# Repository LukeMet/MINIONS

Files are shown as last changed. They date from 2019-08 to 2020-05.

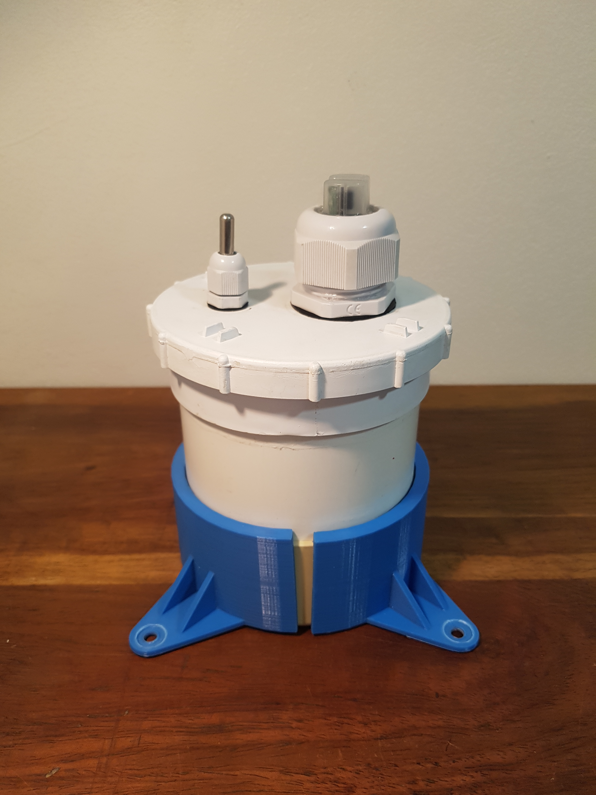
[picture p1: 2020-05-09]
Photos/Construction/2_Lower_SensorModule(i).jpg

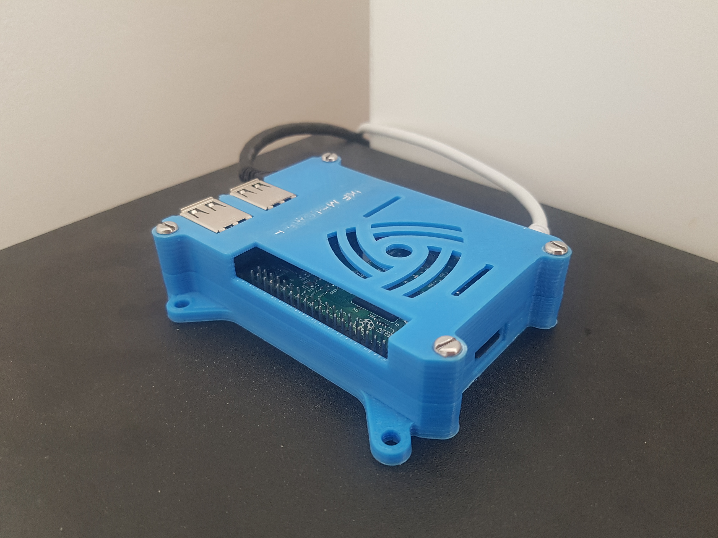
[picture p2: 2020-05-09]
Photos/Construction/4_Server.jpg

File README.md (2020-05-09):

# MINIONS: MarINe Internet Of Nodes Specification
### Luke Metcalfe UCT Mechatronics Final Year Project 2019

Defined a common electrical, mechanical, operational and communication specification for IoT marine monitoring devices and built two prototypes according to the specification. The system comprised of a marine buoy located at sea (Transmitter Node), a base station on land (Receiver Node), and a nearby server. The buoy was equipped with temperature and turbidity sensors, an ESP32 microcontroller, a power supply and management module, and a wireless communications module. Data was transmitted from the buoy to the base station via LoRaWAN. The base station displayed data on an OLED screen and interacted with the server using the MQTT protocol to upload data to an online user interface. Through the interface, users could view all data graphically, receive status updates, and control the buoy remotely.

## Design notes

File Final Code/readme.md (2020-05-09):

Transmitter Node relates to the buoy that was deployed at sea.
Receiver Node relates to the base station on land.
Node-RED Flow relates to the Node-RED Dashboard/user interface.

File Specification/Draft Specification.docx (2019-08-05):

1. General Requirements
  1.1 Designs deviating from the MINIONs specification must ensure complete interoperability and compatibility with existing designs.
  1.2 All parts shall remain attached to the MINIONs during launch and operation. No additional debris shall be created. No MINION may shed any solids or liquids that could be deemed pollution.
  1.3 Total stored chemical energy must not exceed 100 Watt-Hours. (United States Code of Federal Regulations – 49 CFR 175) (100Wh is equivalent to a 5V, 20000mAh battery)
2. Mechanical Requirements
  2.1 General Mechanical Requirements
    2.1.1 MINIONs enclosures should be IP68 and NEMA 6P rated against dust and water for all devices to be deployed above 5m depth. For devices being deployed beyond this depth, designers need to ensure that the enclosure is waterproof at the depth for the duration of the mission at least. (In accordance with ISO 20653:2013 and IEC 60529)
    2.1.2 The enclosure must be fastened to the platform with M4 (ISO 261:1998) nuts and bolts.
    2.1.3 The configuration and physical dimensions shall be defined at a later stage.
    2.1.4 A maximum of 8 MINIONS enclosures can be accommodated on the MINIONS platform.
  2.2 Materials
    2.2.1 All metals used in the construction of the enclosure and platform must be either Type 316 stainless steel (Society of Automotive Engineers (SAE) Steel Grades) or 5052 aluminium (The Alloy Association Inc. International Alloy Designations for Wrought Aluminium Alloys. 5052 formerly designated as AlMg2.5 in ISO 209-1.)
    2.2.2 Where other metals are used, the designer must ensure the chosen metals have similar or better corrosion resistance in marine environments in accordance with ISO9223 and ISO9226. (include corrosion rates of 316 and 5052?)
    2.2.3 All plastic must be HDPE, LDPE or PETG (if 3D printed). (The Society of the Plastics Industry (SPI) Plastic Types)
    2.2.4 Where other plastics are used, the designer must ensure that the material has a water absorption rate less than 0.30% in accordance with ISO62.

ISO 15314:2018 - Plastics -- Methods for marine exposure

3. Electrical Requirements
  3.1 The communication protocol for external busses shall be RS485.
  3.2 The standard supply voltage should be 5V. Many components require this voltage, and this allows both 5V and 3.3V components/peripherals to be used (with the use of level shifters, regulators etc).
  3.3 All MINIONS devices must incorporate battery circuit protection to avoid unbalanced cell conditions. The protection circuitry should ensure charge and discharge voltage limits, charge and discharge current limits and cell-balancing if multiple cells are used. Correct charging and discharging procedures/cycles, specific to the chosen battery, must be followed.
4. Operational Requirements
  4.1 No MINION may shed any solids or liquids that could be deemed pollution.
  4.2 All equipment that is deployed must be retrieved once the mission is complete. No part of the MINION node/s, platform, mooring system, or any other part must remain at sea once the mission is complete.
  4.3 MINIONS must comply with their country’s radio licence agreements and restrictions.
    4.3.1 Standardise LoRa? – Other devices will only be able to talk to mine if they use LoRa

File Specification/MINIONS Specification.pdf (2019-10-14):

# MINIONS

# MarINe Internet Of Nodes Specification

# 1 Introduction

### 1.1 Overview

The MINIONS Specification outlines a general, operational, electrical and mechanical specification to provide a standard for the development of Internet of Things (IoT) marine monitoring devices. The specification lists several requirements of systems and proposes a mechanical design to encourage uniformity and interoperability between devices and networks, as well as the open development of projects between groups.

### 1.2 Purpose

The primary purpose of this document is to define standards for IoT marine monitoring devices to ensure their suitability to the environment, aid cooperation and integration of projects, accelerate development of devices and networks, and accelerate advances in the field.

# 2 Requirements

### 2.1 General Requirements

1.1. Designs deviating from the MINIONS specification must ensure complete interoperability and compatibility with existing designs.
1.2. All parts shall remain attached to the device during launch and operation. No additional debris shall be created.
1.3. Total stored chemical energy must not exceed 100 Watt-Hours [1].

### 2.2 Mechanical Requirements

### 2.2.1 General Mechanical Requirements

1.3.1.Floating platforms shall consist of a floatation device, mounting platform, enclosures and mooring system
1.3.2.Enclosures must be IP68 and NEMA 6P rated against dust and water for all devices to be deployed above 5m depth. For devices being deployed beyond this depth, designers need to ensure that the enclosure is waterproof at the chosen depth for at least the duration of the mission [2][3].

1.3.3.The floatation device used shall be a SOLAS-compliant lifebuoy
1.3.4.The mounting platform shall be secured in the middle of the flotation device. 1.3.5.The platform shall accommodate up to 4 enclosures on its upper and lower surfaces, with a maximum of 8 enclosures in total.
1.3.6.Enclosures shall be fastened to the platform with four M6 [4] nuts, bolts and washers.
Floatation device, mounting platform and enclosure physical dimensions are specified in “

1.3.7.Physical Dimensions of Mechanical Components”.

### 2.2.2 Materials

1.3.8.All metals used in the construction of the enclosure and platform shall be either Type 316 stainless steel or 5052 aluminium.
1.3.9.Where other metals are used, the designer must ensure the chosen metals have similar or better corrosion resistance in marine environments in accordance with ISO 9223 [5] and ISO 9226 [6].
1.3.10. All plastic must be HDPE, LDPE or PETG (if 3D printed).
1.3.11. Where other plastics are used, the designer must ensure that the material has a water absorption rate less than 0.30% in accordance with ISO62 [7], UV resistance similar to that of HDPE, LDPE and PETG, and that the plastic is durable for use at sea in accordance with ISO 15314:2018 [8].

### 2.3 Electrical Requirements

1.4. The communication protocol for external busses shall be RS485.
1.5. No standard supply voltage is specified, as different components require a wide array of supply voltages. Instead, designers must ensure a stable, regulated supply that is able to output the required voltage and current of each component. Special consideration in this regard must be given when interfacing with other MINIONS devices.
1.6. Batteries must comply with Requirement 1.3.
1.7. All MINIONS compliant devices that use batteries must incorporate battery circuit protection to avoid unbalanced cell conditions. The protection circuitry should ensure charge and discharge voltage limits, charge and discharge current limits and cellbalancing if multiple cells are used. Correct charging and discharging procedures/cycles specific to the chosen battery must be followed.
1.8. Wireless communications modules may use WiFi, Bluetooth, LoRa or MQTT technologies.

### 2.4 Operational Requirements

1.9. All equipment that is deployed must be retrieved once the project is complete. No part of the system’s node/s, platform, mooring system, or any other part must remain at sea.
1.10. Approval must be acquired before deploying networks.
1.11. Systems must comply with their country’s radio licence agreements and restrictions.

# 3 Physical Dimensions of Mechanical Components

### 3.1 Floatation device

The floatation device used shall be a SOLAS-compliant lifebuoy, with an outer diameter no greater than 800mm, and inner diameter no less than 400mm [9].

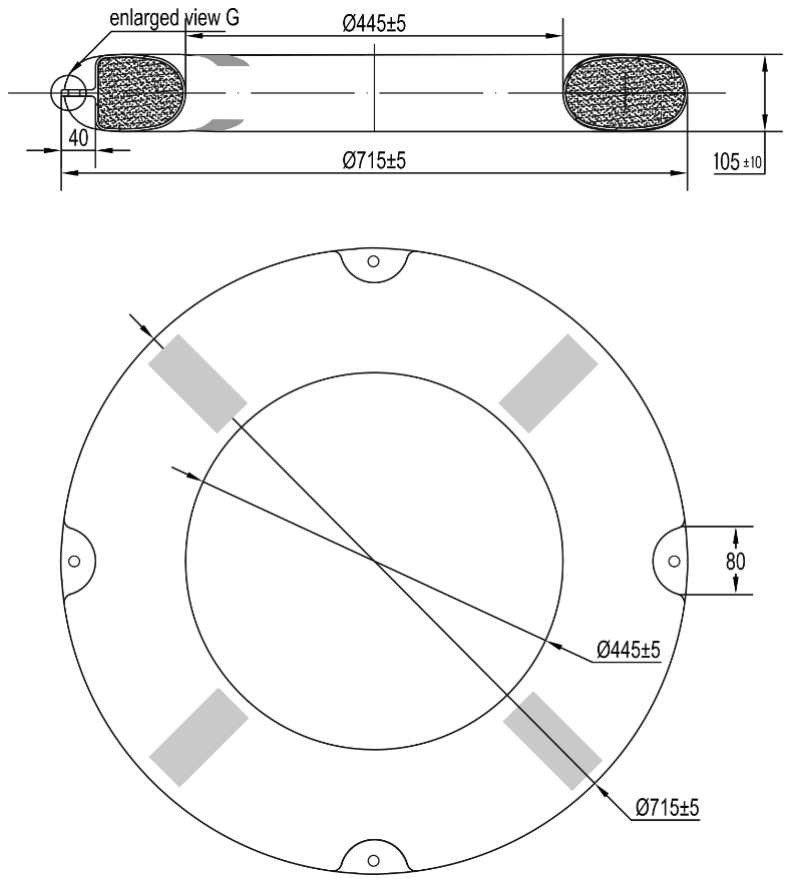
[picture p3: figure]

Figure 1: Illustration of a SOLAS-compliant lifebuoy [10]

### 3.2 Mounting platform

The mounting platform must be circular in shape and cut to fit the internal diameter of the flotation device. It must be possible to fit 4 MINIONS enclosures on each surface. Holes shall be drilled to for the tabs of the MINIONS enclosure must measure 6mm in diameter. The size and layout of the mounting platform are shown below.

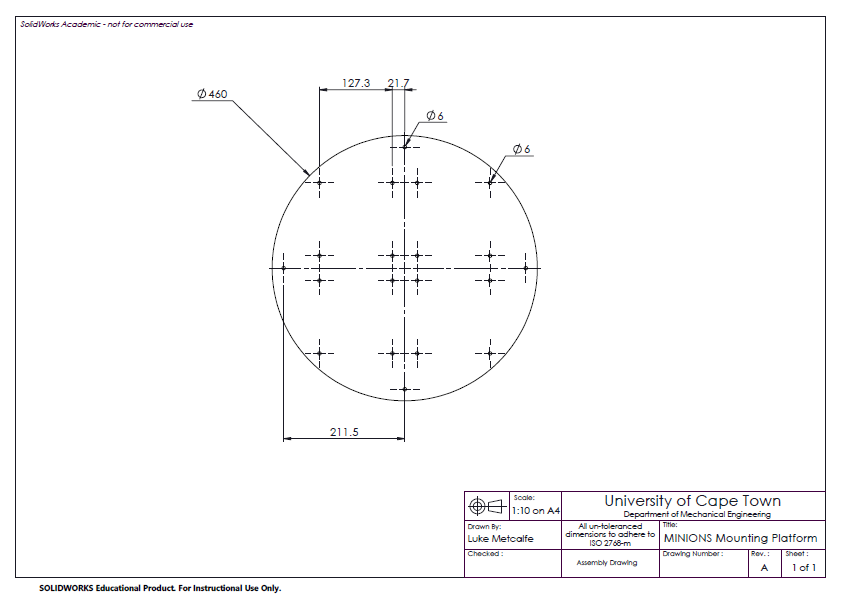
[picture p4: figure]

Figure 2: Top view of the MINIONS mounting platform

### 3.3 Enclosure

The enclosure shall be cylindrical in shape, with a height and diameter of 110mm. The enclosure must have four equally-spaced tabs at its bottom in order to be secured to the mounting platform. The tabs shall have 6mm holes, and the holes should have a pitch of 127.3mm. This corresponds to a diagonal pitch of 180mm apart. Mechanical drawings of the enclosure are shown in Figure 3 to Figure 5 below.

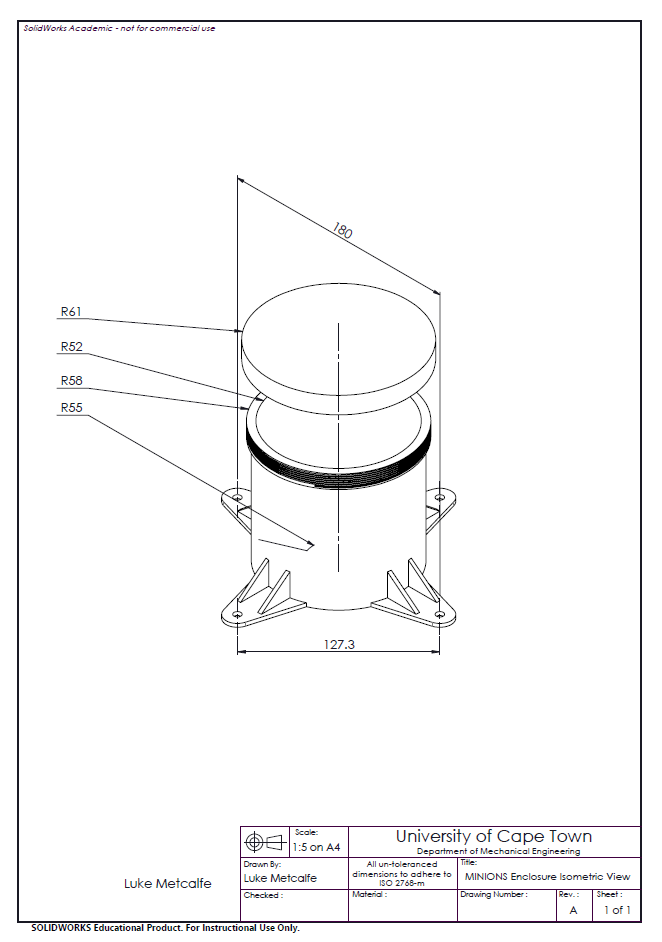
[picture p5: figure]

Figure 3: Isometric view of the MINIONS enclosure

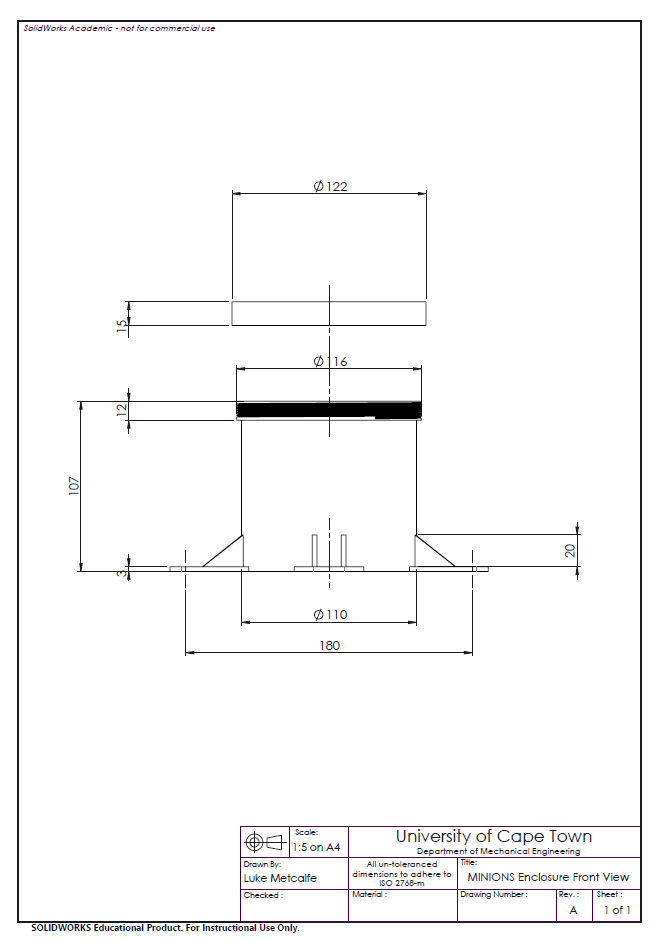
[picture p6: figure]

Figure 4: Front view of the MINIONS enclosure

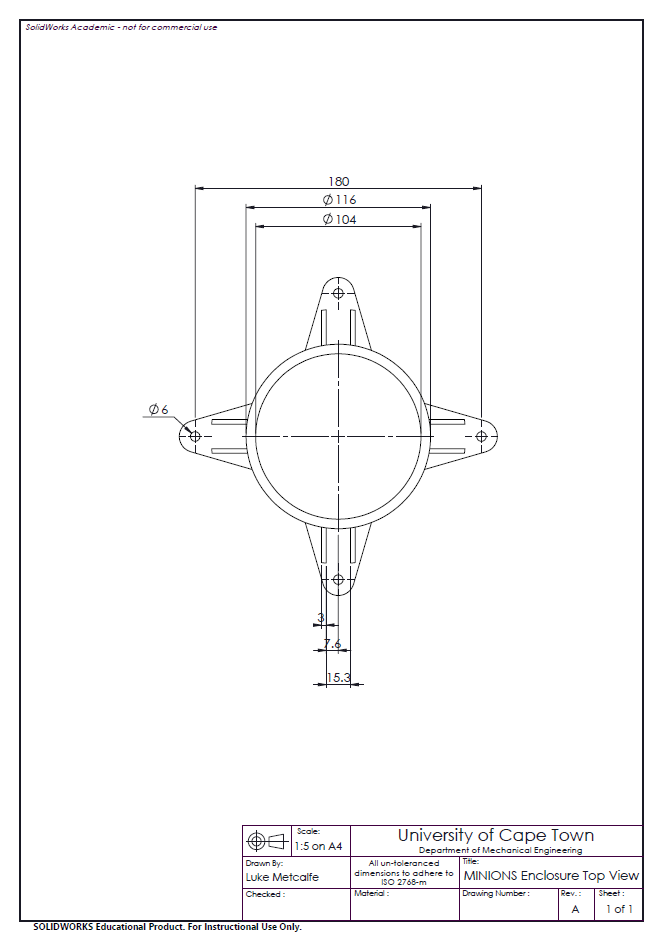
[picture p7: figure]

Figure 5: Top view of the MINIONS enclosure

### 3.4 Assembly

The assembly of the enclosures and mounting platform is shown in Figure 6 below.

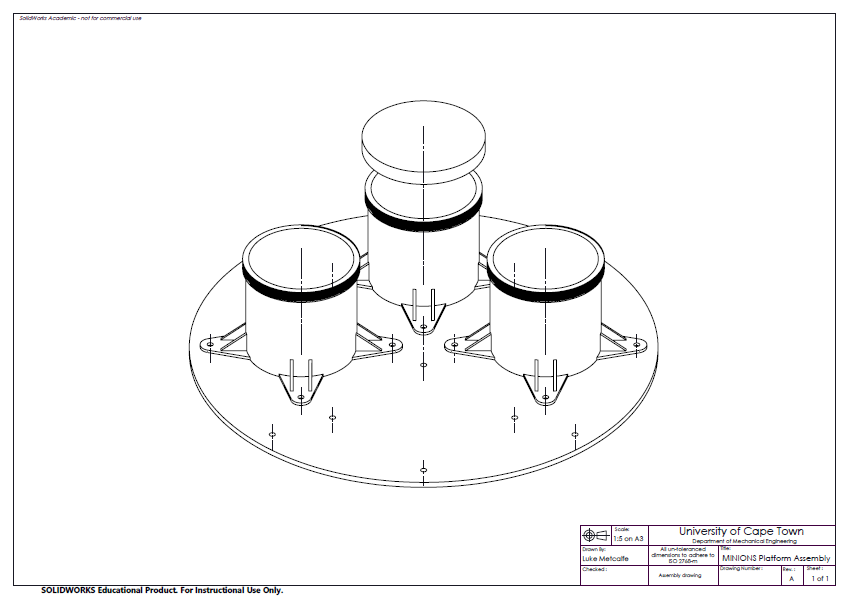
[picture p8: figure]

Figure 6: Isometric view of the assembly of the MINIONS mounting platform and three MINIONS enclosures

# 4 Appendix

References and Cited Standards.

[1] “49 CFR Part 175 - CARRIAGE BY AIRCRAFT | CFR | US Law | LII / Legal Information
Institute.” [Online]. Available: https://www.law.cornell.edu/cfr/text/49/part-175. [Accessed: 12-Oct-2019].
[2] “ISO - ISO 20653:2013 - Road vehicles — Degrees of protection (IP code) — Protection of electrical equipment against foreign objects, water and access.” [Online]. Available: https://www.iso.org/standard/58048.html. [Accessed: 12-Oct-2019].
[3] “IEC 60529:1989+AMD1:1999+AMD2:2013 CSV | IEC Webstore | water management,
smart city, rural electrification.” [Online]. Available: https://webstore.iec.ch/publication/2452. [Accessed: 12-Oct-2019].
[4] “ISO - ISO 261:1998 - ISO general purpose metric screw threads — General plan.” [Online]. Available: https://www.iso.org/standard/4165.html. [Accessed: 12-Oct-2019].
[5] “ISO - ISO 9223:2012 - Corrosion of metals and alloys — Corrosivity of atmospheres — Classification, determination and estimation.” [Online]. Available: https://www.iso.org/standard/53499.html. [Accessed: 12-Oct-2019].
[6] “ISO - ISO 9226:2012 - Corrosion of metals and alloys — Corrosivity of atmospheres — Determination of corrosion rate of standard specimens for the evaluation of corrosivity.” [Online]. Available: https://www.iso.org/standard/53502.html. [Accessed: 12-Oct-2019].
[7] “ISO - ISO 62:2008 - Plastics — Determination of water absorption.” [Online]. Available: https://www.iso.org/standard/41672.html. [Accessed: 12-Oct-2019].
[8] “ISO - ISO 15314:2018 - Plastics — Methods for marine exposure.” [Online]. Available: https://www.iso.org/standard/74668.html. [Accessed: 12-Oct-2019].
[9] “International Convention for the Safety of Life at Sea (SOLAS), 1974.” [Online]. Available: http://www.imo.org/en/About/Conventions/ListOfConventions/Pages/International-Convention-for-the-Safety-of-Life-at-Sea-(SOLAS),-1974.aspx. [Accessed: 12-Oct-2019].
[10] Lalizas, “LALIZAS Lifebuoy Ring SOLAS, with Reflective Tape.” [Online]. Available: https://www.lalizas.com/product/25-lifebuoy-rings/2833-lalizas-lifebuoy-ring-solaswith-reflective-tape. [Accessed: 12-Oct-2019].

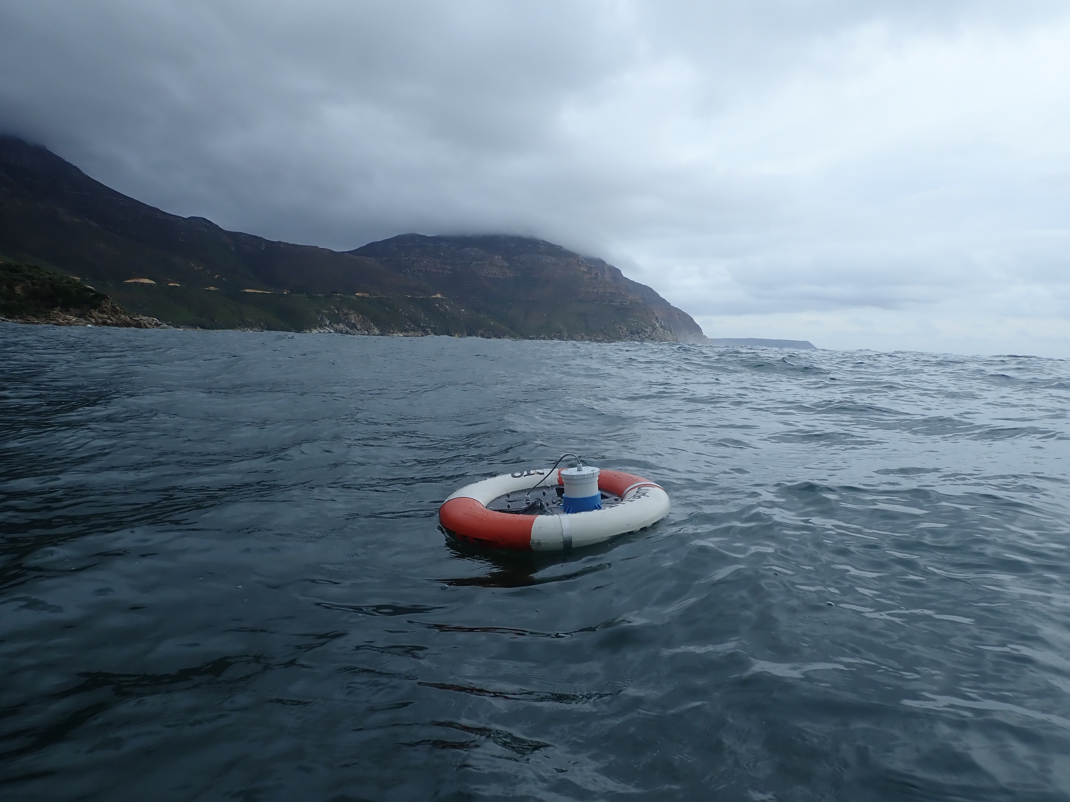
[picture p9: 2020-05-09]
Photos/Deployment/Deploy4.JPG

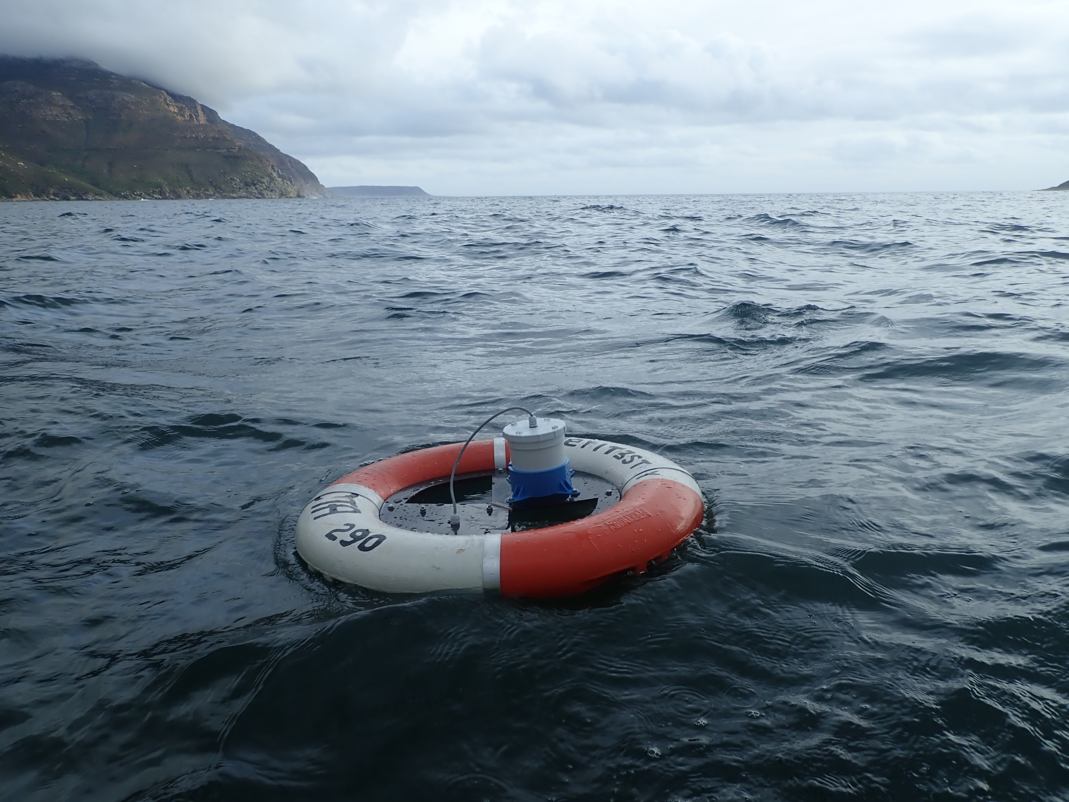
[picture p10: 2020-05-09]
Photos/Deployment/Deploy3.JPG

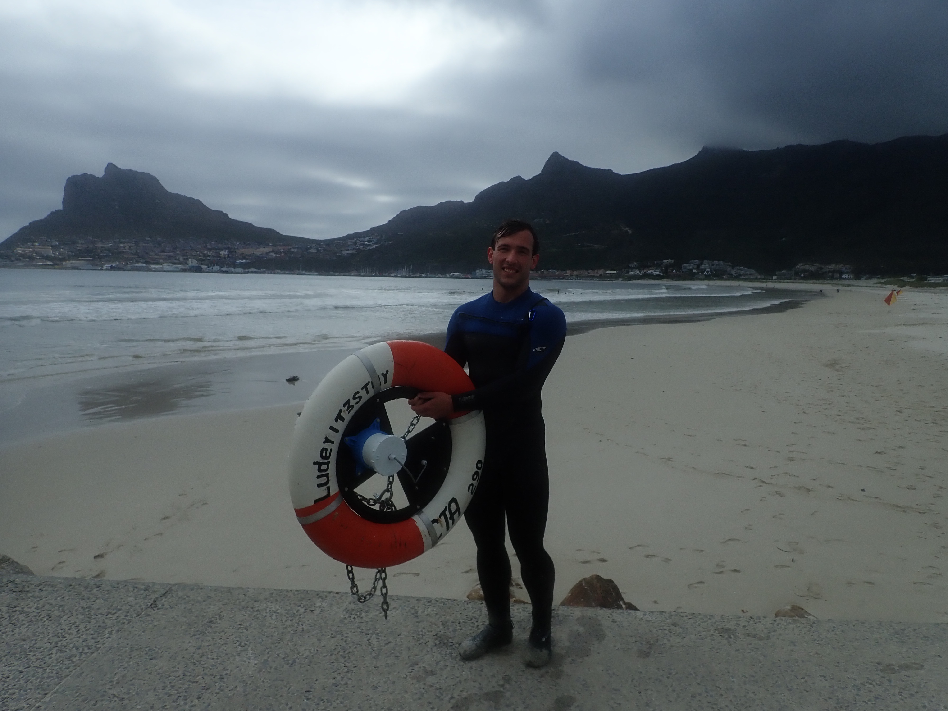
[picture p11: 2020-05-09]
Photos/Deployment/Retreive3.JPG

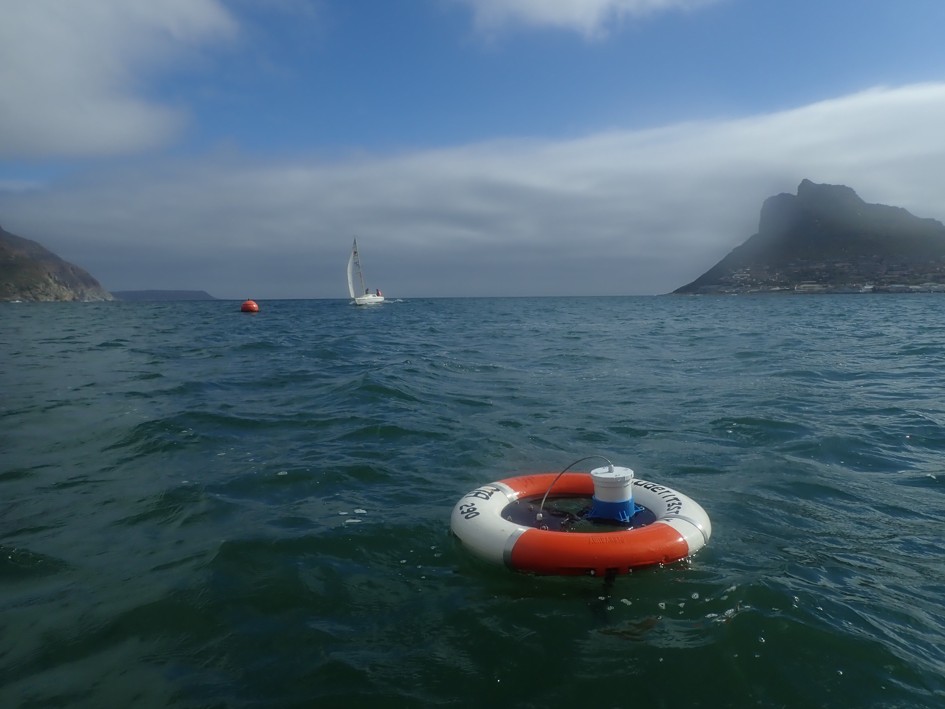
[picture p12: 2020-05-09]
Photos/Deployment/Retreive1.JPG

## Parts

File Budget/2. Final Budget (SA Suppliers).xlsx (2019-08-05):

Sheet: Budget
Complete System
Item No. | Description | Store | Quantity | Unit Cost | Total Cost | Purchase Link
1 | EVAL BOARD FOR ESP-WROOM-32 | Digikey | 2 | 146.1 | 292.2 | https://www.digikey.co.za/product-detail/en/espressif-systems/ESP32-DEVKITC-32D/1965-1000-ND/9356990 | 1
2 | RFM95W LORA RADIO TRANSCEIVER BR (Adafruit) | Digikey | 2 | 291.47 | 582.94 | https://www.digikey.co.za/product-detail/en/adafruit-industries-llc/3072/1528-1667-ND/6005357 | 1
4 | RF Solutions Straight RSMAReverse;Female, Solder Termination, Reverse Polarity | RS Components | 2 | 39.17 | 78.34 | https://za.rs-online.com/web/p/sma-connectors/1258192/ | 1
3 | RF Solutions Antenna FLEXI-SMA-868, Whip SMA 868MHz | RS Components | 2 | 145.1 | 290.2 | https://za.rs-online.com/web/p/telemetry-antennas/0542551/ | 1
5 | GRAVITY: ANALOG TURBIDITY SENSOR | Digikey | 1 | 149.02 | 149.02 | https://www.digikey.co.za/products/en?keywords=sen0189 | 1
6 | DS18B20 WATERPROOF TEMPERATURE SENSOR | DIY Electronics | 1 | 44.95 | 44.95 | https://www.diyelectronics.co.za/store/temperature-sensors/297-waterproof-temperature-sensor.html | 1
 |  |  |  |  | 1437.65
Top Choice
Item No. | Description | Store | Quantity | Unit Cost | Total Cost | Purchase Link
1 | EVAL BOARD FOR ESP-WROOM-32 | Digikey | 2 | 146.1 | 292.2 | https://www.digikey.co.za/product-detail/en/espressif-systems/ESP32-DEVKITC-32D/1965-1000-ND/9356990 | 1
2 | RFM95W LORA RADIO TRANSCEIVER BR (Adafruit) | Digikey | 2 | 291.47 | 582.94 | https://www.digikey.co.za/product-detail/en/adafruit-industries-llc/3072/1528-1667-ND/6005357 | 1
4 | RF Solutions Straight RSMAReverse;Female, Solder Termination, Reverse Polarity | RS Components | 2 | 39.17 | 78.34 | https://za.rs-online.com/web/p/sma-connectors/1258192/ | 1
3 | RF Solutions Antenna FLEXI-SMA-868, Whip SMA 868MHz | RS Components | 2 | 145.1 | 290.2 | https://za.rs-online.com/web/p/telemetry-antennas/0542551/ | 1
5 | GRAVITY: ANALOG TURBIDITY SENSOR | Digikey | 1 | 149.02 | 149.02 | https://www.digikey.co.za/products/en?keywords=sen0189 | 1
6 | DS18B20 WATERPROOF TEMPERATURE SENSOR | DIY Electronics | 1 | 44.95 | 44.95 | https://www.diyelectronics.co.za/store/temperature-sensors/297-waterproof-temperature-sensor.html | 1
 |  |  |  |  | 1437.65

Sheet: Data
Description | Store | Unit Cost | Purchase Link
Micros
ESP-32 Dev Board | Micro Robotics | 159 | https://www.robotics.org.za/espressif%20/ESP-32DEV | 1
BSK ESP-32 WIFI B/T DEV BOARD | Communica | 175 | https://www.communica.co.za/products/bsk-esp-32-wifi-b-t-dev-board | 1
EVAL BOARD FOR ESP-WROOM-32 | Digikey | 146.1 | https://www.digikey.co.za/product-detail/en/espressif-systems/ESP32-DEVKITC-32D/1965-1000-ND/9356990 | 1
LoRa Modules
SX1278 LoRa Module 433Mhz 10Km | Micro Robotics | 139 | https://www.robotics.org.za/%20SX1278-433?search=lora | 1
RFM95W LORA RADIO TRANSCEIVER BR (Adafruit) | Digikey | 291.47 | https://www.digikey.co.za/product-detail/en/adafruit-industries-llc/3072/1528-1667-ND/6005357 | 1
Adafruit RFM95W LoRa Radio Transceiver Breakout - 868 or 915 MHz | Micro Robotics | 398 | https://www.robotics.org.za/AF3072?search=lora | 1
Antennae
RF Solutions Antenna FLEXI-SMA-868, Whip SMA 868MHz | RS Components | 145.1 | https://za.rs-online.com/web/p/telemetry-antennas/0542551/ | 1
Connectors
ACM IPEX TO SMA ANTENA ADPT 10CM | Communica | 39 | https://www.communica.co.za/products/acm-ipex-to-sma-antena-adpt-10cm | 1 | If SX1278 Lora is used
RF Solutions Straight RSMAReverse;Female, Solder Termination, Reverse Polarity | RS Components | 39.17 | https://za.rs-online.com/web/p/sma-connectors/1258192/ | 1 | If Adafruit LoRa used
Turbidity Sensors
DFR ANALOG TURBIDITY SENSOR | Communica | 220 | https://www.communica.co.za/products/dfr-analog-turbidity-sensor | 1
GRAVITY: ANALOG TURBIDITY SENSOR | Digikey | 149.02 | https://www.digikey.co.za/products/en?keywords=sen0189 | 1
Temperature Sensors
CMU TEMPERATURE PROBE DS18B20 | Communica | 40 | https://www.communica.co.za/products/cmu-temperature-probe-ds18b20?variant=17185405370441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 | 1
Temperature Sensor - Waterproof (DS18B20) | Riecktron | 249 | https://www.riecktron.co.za/product/1690 | 1
DS18B20 WATERPROOF TEMPERATURE SENSOR | DIY Electronics | 44.95 | https://www.diyelectronics.co.za/store/temperature-sensors/297-waterproof-temperature-sensor.html | 1

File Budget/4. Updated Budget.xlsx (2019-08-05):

Complete System
Item No. | Description | Store | Quantity | Unit Cost | Total Cost | Purchase Link | Alternative Link | Datasheet Link
1 | ESP32-DevKitC | Mouser | 2 | 142.17 | 284.33 | https://www.mouser.co.za/ProductDetail/Espressif-Systems/ESP32-DevKitC | https://www.amazon.com/Espressif-ESP32-ESP32-DEVKITC-ESP-WROOM-32-soldered/dp/B01N0SB08Q?s=gateway
2 | REYAX RYLR406 Lora Module 433MHz | Amazon | 2 | 276.12 | 552.24 | https://www.amazon.com/RYLR896-Module-SX1276-Antenna-Command/dp/B07NB3BK5H?s=gateway
3 | Waterproof DS18B20 Digital Temperature Sensor for Arduino | Mouser | 1 | 97.70 | 97.70 | https://www.mouser.co.za/ProductDetail/DFRobot/DFR0198?qs=Zcin8yvlhnPOt9ZkO3roFQ%3D%3D | https://www.dfrobot.com/product-689.html
4 | Gravity: Analog Turbidity Sensor For Arduino | Mouser | 1 | 140.18 | 140.18 | https://www.mouser.co.za/ProductDetail/DFRobot/SEN0189 | https://www.dfrobot.com/product-1394.html
5 | MT3608 DC-DC Boost Converter | Mantech | 1 | 42.84 | 42.84 | https://www.mantech.co.za/ProductInfo.aspx?Item=15M0257-A
6 | TP4056 Li-Ion Charging/Protection Board | Communica | 2 | 21.00 | 42.00 | https://www.communica.co.za/products/bsk-lithium-chargr-board-5v-1a
7 | Samsung Li-Ion Cell 3.7V 2500mAh | Mantech | 1 | 115.83 | 115.83 | https://www.mantech.co.za/ProductInfo.aspx?Item=15M1881
8 | LC18650 Battery holder | Communica | 2 | 17.25 | 34.50 | https://www.communica.co.za/products/cmu-1xlc18650-batt-holder-w-pins
 |  |  |  |  | 1309.63
Base Station
Item No. | Description | Store | Quantity | Unit Cost | Total Cost | Purchase Link | Alternative Link | Datasheet Link
1 | ESP32-DevKitC | Mouser | 1 | 142.17 | 142.17 | https://www.mouser.co.za/ProductDetail/Espressif-Systems/ESP32-DevKitC | https://www.amazon.com/Espressif-ESP32-ESP32-DEVKITC-ESP-WROOM-32-soldered/dp/B01N0SB08Q?s=gateway
2 | REYAX RYLR406 Lora Module 433MHz | Amazon | 1 | 276.12 | 276.12 | https://www.amazon.com/RYLR896-Module-SX1276-Antenna-Command/dp/B07NB3BK5H?s=gateway
 |  |  |  |  | 418.29
Charger
Item No. | Description | Store | Quantity | Unit Cost | Total Cost | Purchase Link | Alternative Link | Datasheet Link
6 | TP4056 Li-Ion Charging/Protection Board | Communica | 1 | 21.00 | 21.00 | https://www.communica.co.za/products/bsk-lithium-chargr-board-5v-1a
8 | LC18650 Battery holder | Communica | 1 | 17.25 | 17.25 | https://www.communica.co.za/products/cmu-1xlc18650-batt-holder-w-pins
 |  |  |  |  | 38.25
Node 1
Item No. | Description | Store | Quantity | Unit Cost | Total Cost | Purchase Link | Alternative Link | Datasheet Link
1 | ESP32-DevKitC | Mouser | 1 | 142.17 | 142.17 | https://www.mouser.co.za/ProductDetail/Espressif-Systems/ESP32-DevKitC | https://www.amazon.com/Espressif-ESP32-ESP32-DEVKITC-ESP-WROOM-32-soldered/dp/B01N0SB08Q?s=gateway
2 | REYAX RYLR406 Lora Module 433MHz | Amazon | 1 | 276.12 | 276.12 | https://www.amazon.com/RYLR896-Module-SX1276-Antenna-Command/dp/B07NB3BK5H?s=gateway
3 | Waterproof DS18B20 Digital Temperature Sensor for Arduino | Mouser | 1 | 97.70 | 97.70 | https://www.mouser.co.za/ProductDetail/DFRobot/DFR0198?qs=Zcin8yvlhnPOt9ZkO3roFQ%3D%3D | https://www.dfrobot.com/product-689.html
4 | Gravity: Analog Turbidity Sensor For Arduino | Mouser | 1 | 140.18 | 140.18 | https://www.mouser.co.za/ProductDetail/DFRobot/SEN0189 | https://www.dfrobot.com/product-1394.html
5 | MT3608 DC-DC Boost Converter | Mantech | 1 | 42.84 | 42.84 | https://www.mantech.co.za/ProductInfo.aspx?Item=15M0257-A
6 | TP4056 Li-Ion Charging/Protection Board | Communica | 1 | 21.00 | 21.00 | https://www.communica.co.za/products/bsk-lithium-chargr-board-5v-1a
7 | Samsung Li-Ion Cell 3.7V 2500mAh | Mantech | 1 | 115.83 | 115.83 | https://www.mantech.co.za/ProductInfo.aspx?Item=15M1881
8 | LC18650 Battery holder | Communica | 1 | 17.25 | 17.25 | https://www.communica.co.za/products/cmu-1xlc18650-batt-holder-w-pins
 |  |  |  |  | 853.09
Summary |  | ZAR | Over/Under (ZAR)
Base Station + Node 1 with 2 sensors |  | 1309.63 | -190.3692

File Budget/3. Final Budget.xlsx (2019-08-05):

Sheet: Mouser, Amazon (Reyax)
Complete System
Item No. | Description | Store | Quantity | Unit Cost | Total Cost | Purchase Link | Alternative Link | Datasheet Link
1 | ESP32-DevKitC | Mouser | 2 | 10.04 | 20.08 | https://www.mouser.co.za/ProductDetail/Espressif-Systems/ESP32-DevKitC | https://www.amazon.com/Espressif-ESP32-ESP32-DEVKITC-ESP-WROOM-32-soldered/dp/B01N0SB08Q?s=gateway
2 | REYAX RYLR406 Lora Module 433MHz | Amazon | 2 | 19.5 | 39 | https://www.amazon.com/RYLR896-Module-SX1276-Antenna-Command/dp/B07NB3BK5H?s=gateway
3 | Waterproof DS18B20 Digital Temperature Sensor for Arduino | Mouser | 1 | 6.9 | 6.9 | https://www.mouser.co.za/ProductDetail/DFRobot/DFR0198?qs=Zcin8yvlhnPOt9ZkO3roFQ%3D%3D | https://www.dfrobot.com/product-689.html
4 | Gravity: Analog Turbidity Sensor For Arduino | Mouser | 1 | 9.9 | 9.9 | https://www.mouser.co.za/ProductDetail/DFRobot/SEN0189 | https://www.dfrobot.com/product-1394.html
 |  |  |  |  | 75.88
Base Station
Item No. | Description | Store | Quantity | Unit Cost | Total Cost | Purchase Link | Alternative Link | Datasheet Link
1 | ESP32-DevKitC | Mouser | 1 | 10.04 | 10.04 | https://www.mouser.co.za/ProductDetail/Espressif-Systems/ESP32-DevKitC | https://www.amazon.com/Espressif-ESP32-ESP32-DEVKITC-ESP-WROOM-32-soldered/dp/B01N0SB08Q?s=gateway
2 | REYAX RYLR896 Lora Module 868MHz | Amazon | 1 | 19.5 | 19.5 | https://www.amazon.com/RYLR896-Module-SX1276-Antenna-Command/dp/B07NB3BK5H?s=gateway
 |  |  |  |  | 29.54
Node 1
Item No. | Description | Store | Quantity | Unit Cost | Total Cost | Purchase Link | Alternative Link | Datasheet Link
1 | ESP32-DevKitC | Mouser | 1 | 10.04 | 10.04 | https://www.mouser.co.za/ProductDetail/Espressif-Systems/ESP32-DevKitC | https://www.amazon.com/Espressif-ESP32-ESP32-DEVKITC-ESP-WROOM-32-soldered/dp/B01N0SB08Q?s=gateway
2 | REYAX RYLR896 Lora Module 868MHz | Amazon | 1 | 19.5 | 19.5 | https://www.amazon.com/RYLR896-Module-SX1276-Antenna-Command/dp/B07NB3BK5H?s=gateway
3 | Waterproof DS18B20 Digital Temperature Sensor for Arduino | Mouser | 1 | 6.9 | 6.9 | https://www.mouser.co.za/ProductDetail/DFRobot/DFR0198?qs=Zcin8yvlhnPOt9ZkO3roFQ%3D%3D | https://www.dfrobot.com/product-689.html
4 | Gravity: Analog Turbidity Sensor For Arduino | Mouser | 1 | 9.9 | 9.9 | https://www.mouser.co.za/ProductDetail/DFRobot/SEN0189 | https://www.dfrobot.com/product-1394.html
 |  |  |  |  | 46.34
Summary |  | USD | ZAR | Over/Under (ZAR)
Base Station + Node 1 with 2 sensors |  | 75.88 | 1074.4608 | -425.5392
Mouser
Purchase | 36.96
Shipping | 7.99
Tax | 3.15
Amazon |  |  |  |  |  |  | Amazon Shipping Options
Purchase | 39 |  |  |  |  |  | Prime - 12 July | 0
Shipping (Select date with dropdown) |  |  |  |  |  |  | 16-19 July | 0
16-19 July | 0 |  |  |  |  |  | 12 July | 11.07
Tax | 2.74 |  |  |  |  |  | 11 July | 18.15
Total (USD) | 89.84
Total (ZAR) | 1272.1344
Over/Under (w/ Shipping & Tax) (ZAR) | -227.8656
Shipping Quotes as of 10 July 2019

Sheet: Mouser all (+Antennae)
Complete System
Item No. | Description | Store | Quantity | Unit Cost | Total Cost | Purchase Link | Alternative Link | Datasheet Link
1 | ESP32-DevKitC | Mouser | 2 | 10.04 | 20.08 | https://www.mouser.co.za/ProductDetail/Espressif-Systems/ESP32-DevKitC | https://www.amazon.com/Espressif-ESP32-ESP32-DEVKITC-ESP-WROOM-32-soldered/dp/B01N0SB08Q?s=gateway
2 | Adafruit (PID 3072) RFM95W LoRa Radio Transceiver Breakout - 868 or 915 MHz | Mouser | 2 | 19.95 | 39.9 | https://www.mouser.com/ProductDetail/Adafruit/3072?qs=sGAEpiMZZMudZehw8RjeZcpQM3rZzdL5K14SzjKQYrw%3D | https://www.amazon.com/Adafruit-RFM95W-Radio-Transceiver-Breakout/dp/B01HYO608A?s=gateway
3 | ANT-868-ID-1000-SMA (Antenna) | Mouser | 2 | 18.43 | 36.86 | https://www.mouser.co.za/Search/Refine?FS=TRUE | https://www.mouser.co.za/datasheet/2/238/Linx_09292017_ANT-868-ID%20Data%20Sheet%20170913-1175044.pdf
4 | Waterproof DS18B20 Digital Temperature Sensor for Arduino | Mouser | 1 | 6.9 | 6.9 | https://www.mouser.co.za/ProductDetail/DFRobot/DFR0198?qs=Zcin8yvlhnPOt9ZkO3roFQ%3D%3D | https://www.dfrobot.com/product-689.html
5 | Gravity: Analog Turbidity Sensor For Arduino | Mouser | 1 | 9.9 | 9.9 | https://www.mouser.co.za/ProductDetail/DFRobot/SEN0189 | https://www.dfrobot.com/product-1394.html
 |  |  |  |  | 113.64
Base Station
Item No. | Description | Store | Quantity | Unit Cost | Total Cost | Purchase Link | Alternative Link | Datasheet Link
1 | ESP32-DevKitC | Mouser | 1 | 10.04 | 10.04 | https://www.mouser.co.za/ProductDetail/Espressif-Systems/ESP32-DevKitC | https://www.amazon.com/Espressif-ESP32-ESP32-DEVKITC-ESP-WROOM-32-soldered/dp/B01N0SB08Q?s=gateway
2 | Adafruit (PID 3072) RFM95W LoRa Radio Transceiver Breakout - 868 or 915 MHz | Mouser | 1 | 19.95 | 19.95 | https://www.mouser.com/ProductDetail/Adafruit/3072?qs=sGAEpiMZZMudZehw8RjeZcpQM3rZzdL5K14SzjKQYrw%3D | https://www.amazon.com/Adafruit-RFM95W-Radio-Transceiver-Breakout/dp/B01HYO608A?s=gateway
3 | ANT-868-ID-1000-SMA (Antenna) | Mouser | 1 | 18.43 | 18.43 | https://www.mouser.co.za/Search/Refine?FS=TRUE | https://www.mouser.co.za/datasheet/2/238/Linx_09292017_ANT-868-ID%20Data%20Sheet%20170913-1175044.pdf
 |  |  |  |  | 48.42
Node 1
Item No. | Description | Store | Quantity | Unit Cost | Total Cost | Purchase Link | Alternative Link | Datasheet Link
1 | ESP32-DevKitC | Mouser | 1 | 10.04 | 10.04 | https://www.mouser.co.za/ProductDetail/Espressif-Systems/ESP32-DevKitC | https://www.amazon.com/Espressif-ESP32-ESP32-DEVKITC-ESP-WROOM-32-soldered/dp/B01N0SB08Q?s=gateway
2 | Adafruit (PID 3072) RFM95W LoRa Radio Transceiver Breakout - 868 or 915 MHz | Mouser | 1 | 19.95 | 19.95 | https://www.mouser.com/ProductDetail/Adafruit/3072?qs=sGAEpiMZZMudZehw8RjeZcpQM3rZzdL5K14SzjKQYrw%3D | https://www.amazon.com/Adafruit-RFM95W-Radio-Transceiver-Breakout/dp/B01HYO608A?s=gateway
3 | ANT-868-ID-1000-SMA (Antenna) | Mouser | 1 | 18.43 | 18.43 | https://www.mouser.co.za/Search/Refine?FS=TRUE | https://www.mouser.co.za/datasheet/2/238/Linx_09292017_ANT-868-ID%20Data%20Sheet%20170913-1175044.pdf
4 | Waterproof DS18B20 Digital Temperature Sensor for Arduino | Mouser | 1 | 6.9 | 6.9 | https://www.mouser.co.za/ProductDetail/DFRobot/DFR0198?qs=Zcin8yvlhnPOt9ZkO3roFQ%3D%3D | https://www.dfrobot.com/product-689.html
5 | Gravity: Analog Turbidity Sensor For Arduino | Mouser | 1 | 9.9 | 9.9 | https://www.mouser.co.za/ProductDetail/DFRobot/SEN0189 | https://www.dfrobot.com/product-1394.html
 |  |  |  |  | 65.22
Summary |  | USD | ZAR | Over/Under (ZAR)
Base Station + Node 1 with 2 sensors |  | 113.64 | 1609.1424 | 109.1424
Mouser
Purchase | 113.64
Shipping | 8.89
Tax | 8.59
Total (USD) | 131.12
Total (ZAR) | 1856.6592
Over/Under (w/ Shipping & Tax) (ZAR) | 356.6592
Shipping Quotes as of 10 July 2019

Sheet: Amazon (ESP+Reyax), DF Robot
Complete System
Item No. | Description | Store | Quantity | Unit Cost | Total Cost | Purchase Link | Alternative Link | Datasheet Link
1 | ESP32-DevKitC | Amazon | 2 | 14.95 | 29.9 | https://www.amazon.com/Espressif-ESP32-ESP32-DEVKITC-ESP-WROOM-32-soldered/dp/B01N0SB08Q?s=gateway | https://www.mouser.co.za/ProductDetail/Espressif-Systems/ESP32-DevKitC
2 | REYAX RYLR896 Lora Module 868MHz | Amazon | 2 | 19.5 | 39 | https://www.amazon.com/RYLR896-Module-SX1276-Antenna-Command/dp/B07NB3BK5H?s=gateway
4 | Waterproof DS18B20 Digital Temperature Sensor for Arduino | DFRobot | 1 | 6.9 | 6.9 | https://www.dfrobot.com/product-689.html | https://www.mouser.co.za/ProductDetail/DFRobot/DFR0198?qs=Zcin8yvlhnPOt9ZkO3roFQ%3D%3D
5 | Gravity: Analog Turbidity Sensor For Arduino | DFRobot | 1 | 9.9 | 9.9 | https://www.dfrobot.com/product-1394.html | https://www.mouser.co.za/ProductDetail/DFRobot/SEN0189
 |  |  |  |  | 85.7
Base Station
Item No. | Description | Store | Quantity | Unit Cost | Total Cost | Purchase Link | Alternative Link | Datasheet Link
1 | ESP32-DevKitC | Amazon | 1 | 14.59 | 14.59 | https://www.amazon.com/Espressif-ESP32-ESP32-DEVKITC-ESP-WROOM-32-soldered/dp/B01N0SB08Q?s=gateway | https://www.mouser.co.za/ProductDetail/Espressif-Systems/ESP32-DevKitC
2 | REYAX RYLR896 Lora Module 868MHz | Amazon | 1 | 19.5 | 19.5 | https://www.amazon.com/RYLR896-Module-SX1276-Antenna-Command/dp/B07NB3BK5H?s=gateway
 |  |  |  |  | 34.09
Node 1
Item No. | Description | Store | Quantity | Unit Cost | Total Cost | Purchase Link | Alternative Link | Datasheet Link
1 | ESP32-DevKitC | Amazon | 1 | 14.59 | 14.59 | https://www.amazon.com/Espressif-ESP32-ESP32-DEVKITC-ESP-WROOM-32-soldered/dp/B01N0SB08Q?s=gateway | https://www.mouser.co.za/ProductDetail/Espressif-Systems/ESP32-DevKitC
2 | REYAX RYLR896 Lora Module 868MHz | Amazon | 1 | 19.5 | 19.5 | https://www.amazon.com/RYLR896-Module-SX1276-Antenna-Command/dp/B07NB3BK5H?s=gateway
4 | Waterproof DS18B20 Digital Temperature Sensor for Arduino | DFRobot | 1 | 6.9 | 6.9 | https://www.dfrobot.com/product-689.html | https://www.mouser.co.za/ProductDetail/DFRobot/DFR0198?qs=Zcin8yvlhnPOt9ZkO3roFQ%3D%3D
5 | Gravity: Analog Turbidity Sensor For Arduino | DFRobot | 1 | 9.9 | 9.9 | https://www.dfrobot.com/product-1394.html | https://www.mouser.co.za/ProductDetail/DFRobot/DFR0198?qs=Zcin8yvlhnPOt9ZkO3roFQ%3D%3D
 |  |  |  |  | 50.89
Summary |  | USD | ZAR | Over/Under (ZAR)
Base Station + Node 1 with 2 sensors |  | 85.7 | 1213.512 | -286.488
DF Robot
Purchase | 16.8
Shipping
15-17 July | 16
Tax | 1.18
 |  |  |  |  |  |  |  | Amazon Shipping Options
Amazon |  |  |  |  |  |  |  | Prime - 12 July | 0
Purchase | 68.9 |  |  |  |  |  |  | 16-19 July | 0
Shipping (Select date with dropdown) |  |  |  |  |  |  |  | 12 July | 11.15
16-19 July | 0 |  |  |  |  |  |  | 11 July | 22.61
Tax | 4.84
Total (USD) | 107.72
Total (ZAR) | 1525.3152
Over/Under (w/ Shipping & Tax) (ZAR) | 25.3152
Shipping Quotes as of 10 July 2019

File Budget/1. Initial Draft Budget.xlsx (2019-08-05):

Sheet: Original
This is the first budget I sent, can ignore.
Complete System
Item No. | Description | Store | Quantity | Unit Cost | Total Cost | Purchase Link | Datasheet Link
1 | ARDUINO MKR WiFi 1010 | Amazon | 1 | 35.47 | 35.47 | https://www.amazon.com/Arduino-MKR-WiFi-1010-ABX00023/dp/B07FYFF5YZ?s=gateway
2 | Adafruit (PID 3072) RFM95W LoRa Radio Transceiver Breakout - 868 or 915 MHz | Amazon | 2 | 19 | 38 | https://www.amazon.com/Adafruit-RFM95W-Radio-Transceiver-Breakout/dp/B01HYO608A?s=gateway
3 | ANT-868-ID-1000-SMA (Antenna) | Mouser | 2 | 18.43 | 36.86 | https://www.mouser.co.za/Search/Refine?FS=TRUE | https://www.mouser.co.za/datasheet/2/238/Linx_09292017_ANT-868-ID%20Data%20Sheet%20170913-1175044.pdf
4 | ARDUINO UNO R3 | Amazon | 2 | 18.79 | 37.58 | https://www.amazon.com/Arduino-A000066-ARDUINO-UNO-R3/dp/B008GRTSV6?s=gateway
5 | 3.7V 5000mAh Rechargeable Li-Po Battery |  | 2 | 12.52 | 25.04 | https://www.amazon.com/ZCHXD-alimentaci%C3%B3n-5000mAh-Recargable-pol%C3%ADmero/dp/B07SSWVZ8R?s=gateway
 |  |  |  |  | 172.95
Base Station
Item No. | Description | Store | Quantity | Unit Cost | Total Cost | Purchase Link | Datasheet Link
1 | ARDUINO MKR WiFi 1010 | Amazon | 1 | 35.47 | 35.47 | https://www.amazon.com/Arduino-MKR-WiFi-1010-ABX00023/dp/B07FYFF5YZ?s=gateway
2 | Adafruit (PID 3072) RFM95W LoRa Radio Transceiver Breakout - 868 or 915 MHz | Amazon | 1 | 19 | 19 | https://www.amazon.com/Adafruit-RFM95W-Radio-Transceiver-Breakout/dp/B01HYO608A?s=gateway
3 | ANT-868-ID-1000-SMA (Antenna) | Mouser | 1 | 18.43 | 18.43 | https://www.mouser.co.za/Search/Refine?FS=TRUE | https://www.mouser.co.za/datasheet/2/238/Linx_09292017_ANT-868-ID%20Data%20Sheet%20170913-1175044.pdf
 |  |  |  |  | 72.9
Node 1
Item No. | Description | Store | Quantity | Unit Cost | Total Cost | Purchase Link | Datasheet Link
4 | ARDUINO UNO R3 | Amazon | 1 | 18.79 | 18.79 | https://www.amazon.com/Arduino-A000066-ARDUINO-UNO-R3/dp/B008GRTSV6?s=gateway
2 | Adafruit (PID 3072) RFM95W LoRa Radio Transceiver Breakout - 868 or 915 MHz | Amazon | 1 | 19 | 19 | https://www.amazon.com/Adafruit-RFM95W-Radio-Transceiver-Breakout/dp/B01HYO608A?s=gateway
3 | ANT-868-ID-1000-SMA (Antenna) | Mouser | 1 | 18.43 | 18.43 | https://www.mouser.co.za/Search/Refine?FS=TRUE | https://www.mouser.co.za/datasheet/2/238/Linx_09292017_ANT-868-ID%20Data%20Sheet%20170913-1175044.pdf
5 | 3.7V 5000mAh Rechargeable Li-Po Battery |  | 1 | 12.52 | 12.52 | https://www.amazon.com/ZCHXD-alimentaci%C3%B3n-5000mAh-Recargable-pol%C3%ADmero/dp/B07SSWVZ8R?s=gateway
 |  |  |  |  | 68.74
Node 2
Item No. | Description | Store | Quantity | Unit Cost | Total Cost | Purchase Link | Datasheet Link
4 | ARDUINO UNO R3 | Amazon | 1 | 18.79 | 18.79 | https://www.amazon.com/Arduino-A000066-ARDUINO-UNO-R3/dp/B008GRTSV6?s=gateway
5 | 3.7V 5000mAh Rechargeable Li-Po Battery |  | 1 | 12.52 | 12.52 | https://www.amazon.com/ZCHXD-alimentaci%C3%B3n-5000mAh-Recargable-pol%C3%ADmero/dp/B07SSWVZ8R?s=gateway
 |  |  |  |  | 31.31
Permutations |  | USD | ZAR | Over/Under (ZAR)
Complete System, as is |  | 172.95 | 2448.972 | 948.972
Base Station + Node 1 only |  | 141.64 | 2005.6224 | 505.6224
Use personal RPi instead of Arduino MKR 1010 (not ideal) |  | 137.48 | 1946.7168 | 446.7168
I personally buy Arduino MKR 1010 (i.e exclude from budget) |  | 137.48 | 1946.7168 | 446.7168
Use Reyax LoRa Modules with Built-In Antennae |  | 136.09 | 1927.0344 | 427.0344 | Unit Cost of Reyax LoRa Module: $19.50 | https://www.amazon.com/RYLR896-Module-SX1276-Antenna-Command/dp/B07NB3BK5H?s=gateway
Base Station + Node 1, I personally buy Arduino MKR 1010 |  | 106.17 | 1503.3672 | 3.3672
Base Station + Node 1, I personally buy Arduino MKR 1010, Use Reyax LoRa Modules with Built-In Antennae |  | 69.31 | 981.4296 | -518.5704
These prices exclude: |  | (So, best to leave room in budget)
DC/DC Step Up converters (3.7 -> 5v)
Low Drop Out Regulators (If needed - depends on ripple)
Sensors
Cables/wiring
Waterproof Connectors
Enclosures (If unable to 3D print)
O-rings
Nuts, bolts etc.
Breadboards (Perhaps instead of wiring components)
Platform
Possible commercial 3D printing costs
Main costs are:
LoRa
Micro
Batteries

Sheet: Full System
By "Full", I mean two independent nodes communicating via LoRa to the base station on land.
Complete System
Item No. | Description | Store | Quantity | Unit Cost | Total Cost | Purchase Link | Datasheet Link
1 | ESP32-DevKitC | Amazon | 3 | 14.95 | 44.85 | https://www.amazon.com/Espressif-ESP32-ESP32-DEVKITC-ESP-WROOM-32-soldered/dp/B01N0SB08Q?s=gateway
2 | Adafruit (PID 3072) RFM95W LoRa Radio Transceiver Breakout - 868 or 915 MHz | Amazon | 3 | 19 | 57 | https://www.amazon.com/Adafruit-RFM95W-Radio-Transceiver-Breakout/dp/B01HYO608A?s=gateway
3 | ANT-868-ID-1000-SMA (Antenna) | Mouser | 3 | 18.43 | 55.29 | https://www.mouser.co.za/Search/Refine?FS=TRUE | https://www.mouser.co.za/datasheet/2/238/Linx_09292017_ANT-868-ID%20Data%20Sheet%20170913-1175044.pdf
4 | 3.7V 5000mAh Rechargeable Li-Po Battery | Amazon | 2 | 12.52 | 25.04 | https://www.amazon.com/ZCHXD-alimentaci%C3%B3n-5000mAh-Recargable-pol%C3%ADmero/dp/B07SSWVZ8R?s=gateway
5 | Waterproof DS18B20 Digital Temperature Sensor for Arduino | DFRobot | 1 | 6.9 | 6.9 | https://www.dfrobot.com/product-689.html
6 | Gravity: Analog Turbidity Sensor For Arduino | DFRobot | 1 | 9.9 | 9.9 | https://www.dfrobot.com/product-1394.html
 |  |  |  |  | 198.98
Base Station
Item No. | Description | Store | Quantity | Unit Cost | Total Cost | Purchase Link | Datasheet Link
1 | ESP32-DevKitC | Amazon | 1 | 14.95 | 14.95 | https://www.amazon.com/Espressif-ESP32-ESP32-DEVKITC-ESP-WROOM-32-soldered/dp/B01N0SB08Q?s=gateway
2 | Adafruit (PID 3072) RFM95W LoRa Radio Transceiver Breakout - 868 or 915 MHz | Amazon | 1 | 19 | 19 | https://www.amazon.com/Adafruit-RFM95W-Radio-Transceiver-Breakout/dp/B01HYO608A?s=gateway
3 | ANT-868-ID-1000-SMA (Antenna) | Mouser | 1 | 18.43 | 18.43 | https://www.mouser.co.za/Search/Refine?FS=TRUE | https://www.mouser.co.za/datasheet/2/238/Linx_09292017_ANT-868-ID%20Data%20Sheet%20170913-1175044.pdf
 |  |  |  |  | 52.38
Node 1
Item No. | Description | Store | Quantity | Unit Cost | Total Cost | Purchase Link | Datasheet Link
1 | ESP32-DevKitC | Amazon | 1 | 14.95 | 14.95 | https://www.amazon.com/Espressif-ESP32-ESP32-DEVKITC-ESP-WROOM-32-soldered/dp/B01N0SB08Q?s=gateway
2 | Adafruit (PID 3072) RFM95W LoRa Radio Transceiver Breakout - 868 or 915 MHz | Amazon | 1 | 19 | 19 | https://www.amazon.com/Adafruit-RFM95W-Radio-Transceiver-Breakout/dp/B01HYO608A?s=gateway
3 | ANT-868-ID-1000-SMA (Antenna) | Mouser | 1 | 18.43 | 18.43 | https://www.mouser.co.za/Search/Refine?FS=TRUE | https://www.mouser.co.za/datasheet/2/238/Linx_09292017_ANT-868-ID%20Data%20Sheet%20170913-1175044.pdf
4 | 3.7V 5000mAh Rechargeable Li-Po Battery |  | 1 | 12.52 | 12.52 | https://www.amazon.com/ZCHXD-alimentaci%C3%B3n-5000mAh-Recargable-pol%C3%ADmero/dp/B07SSWVZ8R?s=gateway
6 | Gravity: Analog Turbidity Sensor For Arduino | DFRobot | 1 | 9.9 | 9.9 | https://www.dfrobot.com/product-1394.html
 |  |  |  |  | 74.8
Node 2
Item No. | Description | Store | Quantity | Unit Cost | Total Cost | Purchase Link | Datasheet Link
1 | ESP32-DevKitC | Amazon | 1 | 14.95 | 14.95 | https://www.amazon.com/Espressif-ESP32-ESP32-DEVKITC-ESP-WROOM-32-soldered/dp/B01N0SB08Q?s=gateway
2 | Adafruit (PID 3072) RFM95W LoRa Radio Transceiver Breakout - 868 or 915 MHz | Amazon | 1 | 19 | 19 | https://www.amazon.com/Adafruit-RFM95W-Radio-Transceiver-Breakout/dp/B01HYO608A?s=gateway
3 | ANT-868-ID-1000-SMA (Antenna) | Mouser | 1 | 18.43 | 18.43 | https://www.mouser.co.za/Search/Refine?FS=TRUE | https://www.mouser.co.za/datasheet/2/238/Linx_09292017_ANT-868-ID%20Data%20Sheet%20170913-1175044.pdf
4 | 3.7V 5000mAh Rechargeable Li-Po Battery |  | 1 | 12.52 | 12.52 | https://www.amazon.com/ZCHXD-alimentaci%C3%B3n-5000mAh-Recargable-pol%C3%ADmero/dp/B07SSWVZ8R?s=gateway
5 | Waterproof DS18B20 Digital Temperature Sensor for Arduino | DFRobot | 1 | 6.9 | 6.9 | https://www.dfrobot.com/product-689.html
 |  |  |  |  | 64.9
Permutations |  | USD | ZAR | Over/Under (ZAR)
Complete System, as is |  | 198.98 | 2817.5568 | 1317.5568
Use Reyax LoRa Modules with Built-In Antennae |  | 143.69 | 2034.6504 | 534.6504 | Unit Cost of Reyax LoRa Module: $19.50 | https://www.amazon.com/RYLR896-Module-SX1276-Antenna-Command/dp/B07NB3BK5H?s=gateway
These prices exclude: |  | (So, best to leave room in budget)
DC/DC Step Up converters (3.7 -> 5v)
Low Drop Out Regulators (If needed - depends on ripple)
Cables/wiring
Waterproof Connectors
Enclosures (If unable to 3D print)
O-rings
Nuts, bolts etc.
Breadboards (Perhaps instead of wiring components)
Platform
Possible commercial 3D printing costs

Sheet: Node 2 wired with CAN
Complete System
Item No. | Description | Store | Quantity | Unit Cost | Total Cost | Purchase Link | Datasheet Link
1 | ESP32-DevKitC | Amazon | 3 | 14.95 | 44.85 | https://www.amazon.com/Espressif-ESP32-ESP32-DEVKITC-ESP-WROOM-32-soldered/dp/B01N0SB08Q?s=gateway
2 | Adafruit (PID 3072) RFM95W LoRa Radio Transceiver Breakout - 868 or 915 MHz | Amazon | 2 | 19 | 38 | https://www.amazon.com/Adafruit-RFM95W-Radio-Transceiver-Breakout/dp/B01HYO608A?s=gateway
3 | ANT-868-ID-1000-SMA (Antenna) | Mouser | 2 | 18.43 | 36.86 | https://www.mouser.co.za/Search/Refine?FS=TRUE | https://www.mouser.co.za/datasheet/2/238/Linx_09292017_ANT-868-ID%20Data%20Sheet%20170913-1175044.pdf
4 | 3.7V 5000mAh Rechargeable Li-Po Battery | Amazon | 2 | 12.52 | 25.04 | https://www.amazon.com/ZCHXD-alimentaci%C3%B3n-5000mAh-Recargable-pol%C3%ADmero/dp/B07SSWVZ8R?s=gateway
5 | Waterproof DS18B20 Digital Temperature Sensor for Arduino | DFRobot | 1 | 6.9 | 6.9 | https://www.dfrobot.com/product-689.html
6 | Gravity: Analog Turbidity Sensor For Arduino | DFRobot | 1 | 9.9 | 9.9 | https://www.dfrobot.com/product-1394.html
 |  |  |  |  | 161.55
Base Station
Item No. | Description | Store | Quantity | Unit Cost | Total Cost | Purchase Link | Datasheet Link
1 | ESP32-DevKitC | Amazon | 1 | 14.95 | 14.95 | https://www.amazon.com/Espressif-ESP32-ESP32-DEVKITC-ESP-WROOM-32-soldered/dp/B01N0SB08Q?s=gateway
2 | Adafruit (PID 3072) RFM95W LoRa Radio Transceiver Breakout - 868 or 915 MHz | Amazon | 1 | 19 | 19 | https://www.amazon.com/Adafruit-RFM95W-Radio-Transceiver-Breakout/dp/B01HYO608A?s=gateway
3 | ANT-868-ID-1000-SMA (Antenna) | Mouser | 1 | 18.43 | 18.43 | https://www.mouser.co.za/Search/Refine?FS=TRUE | https://www.mouser.co.za/datasheet/2/238/Linx_09292017_ANT-868-ID%20Data%20Sheet%20170913-1175044.pdf
 |  |  |  |  | 52.38
Node 1
Item No. | Description | Store | Quantity | Unit Cost | Total Cost | Purchase Link | Datasheet Link
1 | ESP32-DevKitC | Amazon | 1 | 14.95 | 14.95 | https://www.amazon.com/Espressif-ESP32-ESP32-DEVKITC-ESP-WROOM-32-soldered/dp/B01N0SB08Q?s=gateway
2 | Adafruit (PID 3072) RFM95W LoRa Radio Transceiver Breakout - 868 or 915 MHz | Amazon | 1 | 19 | 19 | https://www.amazon.com/Adafruit-RFM95W-Radio-Transceiver-Breakout/dp/B01HYO608A?s=gateway
3 | ANT-868-ID-1000-SMA (Antenna) | Mouser | 1 | 18.43 | 18.43 | https://www.mouser.co.za/Search/Refine?FS=TRUE | https://www.mouser.co.za/datasheet/2/238/Linx_09292017_ANT-868-ID%20Data%20Sheet%20170913-1175044.pdf
4 | 3.7V 5000mAh Rechargeable Li-Po Battery |  | 1 | 12.52 | 12.52 | https://www.amazon.com/ZCHXD-alimentaci%C3%B3n-5000mAh-Recargable-pol%C3%ADmero/dp/B07SSWVZ8R?s=gateway
6 | Gravity: Analog Turbidity Sensor For Arduino | DFRobot | 1 | 9.9 | 9.9 | https://www.dfrobot.com/product-1394.html
 |  |  |  |  | 74.8
Node 2
Item No. | Description | Store | Quantity | Unit Cost | Total Cost | Purchase Link | Datasheet Link
1 | ESP32-DevKitC | Amazon | 1 | 14.95 | 14.95 | https://www.amazon.com/Espressif-ESP32-ESP32-DEVKITC-ESP-WROOM-32-soldered/dp/B01N0SB08Q?s=gateway
4 | 3.7V 5000mAh Rechargeable Li-Po Battery |  | 1 | 12.52 | 12.52 | https://www.amazon.com/ZCHXD-alimentaci%C3%B3n-5000mAh-Recargable-pol%C3%ADmero/dp/B07SSWVZ8R?s=gateway
5 | Waterproof DS18B20 Digital Temperature Sensor for Arduino | DFRobot | 1 | 6.9 | 6.9 | https://www.dfrobot.com/product-689.html
 |  |  |  |  | 34.37
Permutations |  | USD | ZAR | Over/Under (ZAR)
Full System, but Node 1 wired to Node 2 |  | 161.55 | 2287.548 | 787.548
Use Reyax LoRa Modules with Built-In Antennae |  | 124.69 | 1765.6104 | 265.6104 | Unit Cost of Reyax LoRa Module: $19.50 | https://www.amazon.com/RYLR896-Module-SX1276-Antenna-Command/dp/B07NB3BK5H?s=gateway
These prices exclude: |  | (So, best to leave room in budget)
DC/DC Step Up converters (3.7 -> 5v)
Low Drop Out Regulators (If needed - depends on ripple)
Cables/wiring
Waterproof Connectors
Enclosures (If unable to 3D print)
O-rings
Nuts, bolts etc.
Breadboards (Perhaps instead of wiring components)
Platform
Possible commercial 3D printing costs

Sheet: Node 1 only
Complete System
Item No. | Description | Store | Quantity | Unit Cost | Total Cost | Purchase Link | Datasheet Link
1 | ESP32-DevKitC | Amazon | 2 | 14.95 | 29.9 | https://www.amazon.com/Espressif-ESP32-ESP32-DEVKITC-ESP-WROOM-32-soldered/dp/B01N0SB08Q?s=gateway
2 | Adafruit (PID 3072) RFM95W LoRa Radio Transceiver Breakout - 868 or 915 MHz | Amazon | 2 | 19 | 38 | https://www.amazon.com/Adafruit-RFM95W-Radio-Transceiver-Breakout/dp/B01HYO608A?s=gateway
3 | ANT-868-ID-1000-SMA (Antenna) | Mouser | 2 | 18.43 | 36.86 | https://www.mouser.co.za/Search/Refine?FS=TRUE | https://www.mouser.co.za/datasheet/2/238/Linx_09292017_ANT-868-ID%20Data%20Sheet%20170913-1175044.pdf
4 | 3.7V 5000mAh Rechargeable Li-Po Battery | Amazon | 1 | 12.52 | 12.52 | https://www.amazon.com/ZCHXD-alimentaci%C3%B3n-5000mAh-Recargable-pol%C3%ADmero/dp/B07SSWVZ8R?s=gateway
5 | Waterproof DS18B20 Digital Temperature Sensor for Arduino | DFRobot | 1 | 6.9 | 6.9 | https://www.dfrobot.com/product-689.html
6 | Gravity: Analog Turbidity Sensor For Arduino | DFRobot | 1 | 9.9 | 9.9 | https://www.dfrobot.com/product-1394.html
 |  |  |  |  | 134.08
Base Station
Item No. | Description | Store | Quantity | Unit Cost | Total Cost | Purchase Link | Datasheet Link
1 | ESP32-DevKitC | Amazon | 1 | 14.95 | 14.95 | https://www.amazon.com/Espressif-ESP32-ESP32-DEVKITC-ESP-WROOM-32-soldered/dp/B01N0SB08Q?s=gateway
2 | Adafruit (PID 3072) RFM95W LoRa Radio Transceiver Breakout - 868 or 915 MHz | Amazon | 1 | 19 | 19 | https://www.amazon.com/Adafruit-RFM95W-Radio-Transceiver-Breakout/dp/B01HYO608A?s=gateway
3 | ANT-868-ID-1000-SMA (Antenna) | Mouser | 1 | 18.43 | 18.43 | https://www.mouser.co.za/Search/Refine?FS=TRUE | https://www.mouser.co.za/datasheet/2/238/Linx_09292017_ANT-868-ID%20Data%20Sheet%20170913-1175044.pdf
 |  |  |  |  | 52.38
Node 1
Item No. | Description | Store | Quantity | Unit Cost | Total Cost | Purchase Link | Datasheet Link
1 | ESP32-DevKitC | Amazon | 1 | 14.95 | 14.95 | https://www.amazon.com/Espressif-ESP32-ESP32-DEVKITC-ESP-WROOM-32-soldered/dp/B01N0SB08Q?s=gateway
2 | Adafruit (PID 3072) RFM95W LoRa Radio Transceiver Breakout - 868 or 915 MHz | Amazon | 1 | 19 | 19 | https://www.amazon.com/Adafruit-RFM95W-Radio-Transceiver-Breakout/dp/B01HYO608A?s=gateway
3 | ANT-868-ID-1000-SMA (Antenna) | Mouser | 1 | 18.43 | 18.43 | https://www.mouser.co.za/Search/Refine?FS=TRUE | https://www.mouser.co.za/datasheet/2/238/Linx_09292017_ANT-868-ID%20Data%20Sheet%20170913-1175044.pdf
4 | 3.7V 5000mAh Rechargeable Li-Po Battery |  | 1 | 12.52 | 12.52 | https://www.amazon.com/ZCHXD-alimentaci%C3%B3n-5000mAh-Recargable-pol%C3%ADmero/dp/B07SSWVZ8R?s=gateway
5 | Waterproof DS18B20 Digital Temperature Sensor for Arduino | DFRobot | 1 | 6.9 | 6.9 | https://www.dfrobot.com/product-689.html
6 | Gravity: Analog Turbidity Sensor For Arduino | DFRobot | 1 | 9.9 | 9.9 | https://www.dfrobot.com/product-1394.html
 |  |  |  |  | 71.8
Permutations |  | USD | ZAR | Over/Under (ZAR)
Base Station + Node 1 with 2 sensors |  | 134.08 | 1898.5728 | 398.5728
Use Reyax LoRa Modules with Built-In Antennae |  | 97.22 | 1376.6352 | -123.3648 | Unit Cost of Reyax LoRa Module: $19.50 | https://www.amazon.com/RYLR896-Module-SX1276-Antenna-Command/dp/B07NB3BK5H?s=gateway
These prices exclude: |  | (So, best to leave room in budget)
DC/DC Step Up converters (3.7 -> 5v)
Low Drop Out Regulators (If needed - depends on ripple)
Cables/wiring
Waterproof Connectors
Enclosures (If unable to 3D print)
O-rings
Nuts, bolts etc.
Breadboards (Perhaps instead of wiring components)
Platform
Possible commercial 3D printing costs

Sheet: Cheapest
Complete System
Item No. | Description | Store | Quantity | Unit Cost | Total Cost | Purchase Link | Alternative Link | Datasheet Link
1 | ESP32-DevKitC | Amazon | 2 | 10.04 | 20.08 | https://www.mouser.co.za/ProductDetail/Espressif-Systems/ESP32-DevKitC | https://www.amazon.com/Espressif-ESP32-ESP32-DEVKITC-ESP-WROOM-32-soldered/dp/B01N0SB08Q?s=gateway
2 | REYAX RYLR896 Lora Module 868MHz | Amazon | 2 | 19.5 | 39 | https://www.amazon.com/RYLR896-Module-SX1276-Antenna-Command/dp/B07NB3BK5H?s=gateway
4 | Waterproof DS18B20 Digital Temperature Sensor for Arduino | DFRobot/Mouser | 1 | 6.9 | 6.9 | https://www.mouser.co.za/ProductDetail/DFRobot/DFR0198?qs=Zcin8yvlhnPOt9ZkO3roFQ%3D%3D | https://www.dfrobot.com/product-689.html
5 | Gravity: Analog Turbidity Sensor For Arduino | DFRobot/Mouser | 1 | 9.9 | 9.9 | https://www.mouser.co.za/ProductDetail/DFRobot/SEN0189 | https://www.dfrobot.com/product-1394.html
 |  |  |  |  | 75.88
Base Station
Item No. | Description | Store | Quantity | Unit Cost | Total Cost | Purchase Link | Alternative Link | Datasheet Link
1 | ESP32-DevKitC | Amazon | 1 | 10.04 | 10.04 | https://www.mouser.co.za/ProductDetail/Espressif-Systems/ESP32-DevKitC | https://www.amazon.com/Espressif-ESP32-ESP32-DEVKITC-ESP-WROOM-32-soldered/dp/B01N0SB08Q?s=gateway
2 | REYAX RYLR896 Lora Module 868MHz | Amazon | 1 | 19.5 | 19.5 | https://www.amazon.com/RYLR896-Module-SX1276-Antenna-Command/dp/B07NB3BK5H?s=gateway
 |  |  |  |  | 29.54
Node 1
Item No. | Description | Store | Quantity | Unit Cost | Total Cost | Purchase Link | Alternative Link | Datasheet Link
1 | ESP32-DevKitC | Amazon | 1 | 10.04 | 10.04 | https://www.amazon.com/Espressif-ESP32-ESP32-DEVKITC-ESP-WROOM-32-soldered/dp/B01N0SB08Q?s=gateway
2 | REYAX RYLR896 Lora Module 868MHz | Amazon | 1 | 19.5 | 19.5 | https://www.amazon.com/RYLR896-Module-SX1276-Antenna-Command/dp/B07NB3BK5H?s=gateway
4 | Waterproof DS18B20 Digital Temperature Sensor for Arduino | DFRobot/Mouser | 1 | 6.9 | 6.9 | https://www.mouser.co.za/ProductDetail/DFRobot/DFR0198?qs=Zcin8yvlhnPOt9ZkO3roFQ%3D%3D | https://www.dfrobot.com/product-689.html
5 | Gravity: Analog Turbidity Sensor For Arduino | DFRobot/Mouser | 1 | 9.9 | 9.9 | https://www.mouser.co.za/ProductDetail/DFRobot/SEN0189 | https://www.dfrobot.com/product-1394.html
 |  |  |  |  | 46.34
Summary |  | USD | ZAR | Over/Under (ZAR)
Base Station + Node 1 with 2 sensors |  | 75.88 | 1074.4608 | -425.5392
These prices exclude: |  | (So, best to leave room in budget)
DC/DC Step Up converters (3.7 -> 5v)
Low Drop Out Regulators (If needed - depends on ripple)
Cables/wiring
Waterproof Connectors
Enclosures (If unable to 3D print)
O-rings
Nuts, bolts etc.
Breadboards (Perhaps instead of wiring components)
Platform
Possible commercial 3D printing costs

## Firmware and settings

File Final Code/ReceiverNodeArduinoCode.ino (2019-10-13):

//-------------------------------------------------------------------------------------------
// INCLUDES
//-------------------------------------------------------------------------------------------

// MQTT Includes
#include <WiFi.h>
#include <PubSubClient.h>
#include <Wire.h>

// OLED Includes
#include <Wire.h>
#include <Adafruit_GFX.h>
#include <Adafruit_SSD1306.h>

//-------------------------------------------------------------------------------------------
// VARIABLES
//-------------------------------------------------------------------------------------------

// MQTT Constants and objects
const char* ssid = "Reformat Hard Drive"; // SSID/Password combination
const char* password = "Totolink1234nomore@number4";
const char* mqtt_server = "192.168.1.101"; // MQTT Broker IP address
WiFiClient espClient;
PubSubClient client(espClient);
long lastMsg = 0;
char msg[50];
int value = 0;

// OLED Constants and Objects
#define SCREEN_WIDTH 128 // OLED display width, in pixels
#define SCREEN_HEIGHT 64 // OLED display height, in pixels
Adafruit_SSD1306 display(SCREEN_WIDTH, SCREEN_HEIGHT, &Wire, -1);
int OLEDcount = 0;

// Receive LED
#define ledPin1 2

// Tx State Variables
#define ledPin2 14
String TxState = "SLEEP";

// Sample Period 
String SamplePeriod = "4";
String NewSamplePeriod;
bool ClearToSend = false;
bool QueuedSample = false;
bool QueuedRestart = false;

// OLED Pins
// SCL -> GPIO22
// SDA -> GPIO21

// Text Extraction Variables
String incomingString;
String sendaddress;
String messagesize;
String Temperature;
String Turbidity;
String Voltage;
String PacketNo;
String rssi;
String snr;

//-------------------------------------------------------------------------------------------
// SETUP BELOW
//-------------------------------------------------------------------------------------------

void setup() {
  Serial.begin(115200);
  pinMode(ledPin1, OUTPUT);
  pinMode(ledPin2, OUTPUT);

  // LoRa Rx Setup
  Serial.println("AT+RESET");
  delay(20);
  Serial.println("AT+ADDRESS=1");
  delay(20);
  Serial.println("AT+NETWORKID=5");

  // OLED Setup
  if(!display.begin(SSD1306_SWITCHCAPVCC, 0x3C)) { // Address 0x3C for 128x64
    Serial.println(F("SSD1306 allocation failed"));
    for(;;);
  }
  delay(2000);
  display.clearDisplay();
  display.setTextSize(1);
  display.setTextColor(WHITE);

  // MQTT Setup
  setup_wifi();
  client.setServer(mqtt_server, 1883);
  client.setCallback(callback);

  PublishSamplePeriod();

}

//-------------------------------------------------------------------------------------------
// CODE BEFORE LOOP
//-------------------------------------------------------------------------------------------


//-------------------------------------------------------------------------------------------
// LOOP BELOW
//-------------------------------------------------------------------------------------------

void loop() {

  // Check that Rx is connected to Broker
  if (!client.connected()) {
    reconnect();
  }
  client.loop();

  CheckForMessage();
  CheckClearToSend();

  ScreenSaver();
  
}

//-------------------------------------------------------------------------------------------
// ALL OTHER FUNCTIONS
//-------------------------------------------------------------------------------------------

void setup_wifi() {
  delay(10);
  // We start by connecting to a WiFi network
  Serial.println();
  Serial.print("Connecting to ");
  Serial.println(ssid);

  WiFi.begin(ssid, password);

  // Print to OLED
  display.setCursor(0, 5);
  display.clearDisplay();
  display.println("Connecting");

  while (WiFi.status() != WL_CONNECTED) {
    delay(500);
    // Print to Serial
    Serial.print(".");    

    // Print to OLED
    display.print(".");
    display.display(); 
  }

  // Print to OLED
  display.setCursor(0, 5);
  display.clearDisplay();
  display.println("Connected");
  display.display(); 

  // Print to Serial
  Serial.println("");
  Serial.println("WiFi connected");
  Serial.println("IP address: ");
  Serial.println(WiFi.localIP());
}

void callback(char* topic, byte* message, unsigned int length) {
  Serial.print("Message arrived on topic: ");
  Serial.print(topic);
  Serial.print(". Message: ");
  String messageTemp;
  
  for (int i = 0; i < length; i++) {
    Serial.print((char)message[i]);
    messageTemp += (char)message[i];
  }
  Serial.println();

  // Feel free to add more if statements to control more GPIOs with MQTT

  // If a message is received on the topic esp32/output, you check if the message is either "on" or "off". 
  // Changes the output state according to the message
  if (String(topic) == "esp32/output") {
    Serial.print("Changing output to ");
    if(messageTemp == "on"){
      Serial.println("on");
      // TxWake();
    }
    else if(messageTemp == "off"){
      Serial.println("off");
      // TxSleep();
    }
  }

  if (String(topic) == "esp32/SamplePeriod") {
    // Serial.print("Changing sample period to ");
    // Serial.println(messageTemp);
    NewSamplePeriod = messageTemp;
    QueuedSample = true;
    Serial.println("Sample Period changed to " + NewSamplePeriod + "s - waiting for Tx to wake");
    //ChangeSamplePeriod();
  }

  if (String(topic) == "esp32/restart") {
    QueuedRestart = true;
      // Serial.println("+RCV=0,7,RESTART,-125,-31");
  }
  
}




void reconnect() {
  // Loop until we're reconnected
  while (!client.connected()) {
    Serial.print("Attempting MQTT connection...");
    // Attempt to connect
    if (client.connect("ESP8266Client")) {
      Serial.println("connected");
      // Subscribe
      client.subscribe("esp32/output");
      client.subscribe("esp32/SamplePeriod");
      client.subscribe("esp32/restart");
    } else {
      Serial.print("failed, rc=");
      Serial.print(client.state());
      Serial.println(" try again in 5 seconds");
      // Wait 5 seconds before retrying
      delay(5000);
    }
  }
}

void CheckForMessage(){
  if (Serial.available()>0){

    incomingString = Serial.readString();
  
    if(incomingString.indexOf("RCV") > 0){
      // Filter Messages
      // Data
      if(incomingString.indexOf("DATA") > 0){
        ExtractData();
        Serial.println("Data received");
      }

      // State
      if(incomingString.indexOf("STATE") > 0){
        
        if(incomingString.indexOf("WAKE") > 0){
          digitalWrite(ledPin2, HIGH);
          TxState = "WAKE";
          delay(100);
          Serial.println("Tx awake");
        }
        
        if(incomingString.indexOf("SLEEP") > 0){
          digitalWrite(ledPin2, LOW);
          TxState = "SLEEP";
          delay(100);
          Serial.println("Tx asleep");
          ClearToSend = false;
        }
        UpdateTxStateLED();
      }

      //Clear to Send
      if((incomingString.indexOf("CLEARTOSEND")) > 0){
        ClearToSend = true;
      }

      //Tx Shutdown
      if((incomingString.indexOf("SHUTDOWN")) > 0){
        Serial.println("Tx Battery drained - Tx shutting down");
        PublishShutdown();
      }
      
    }
  }
}

void ExtractData(){
  digitalWrite(ledPin1, HIGH);
  Serial.println(incomingString);
  
  // Find Placeholders
  // If message contains commas, could be problematic. So should use better extraction than commas to make more robust
  int equal = incomingString.indexOf('=');
  int comma1 = incomingString.indexOf(','); // Find comma - beginning of <Payload Length>
  int comma2 = incomingString.indexOf(',', comma1 + 1); // Find second comma, starting from index after the first comma
  int plus1 = incomingString.indexOf('+', comma2 + 1);
  int plus2 = incomingString.indexOf('+', plus1 + 1);
  int plus3 = incomingString.indexOf('+', plus2 + 1);
  int plus4 = incomingString.indexOf('+', plus3 + 1);
  int comma3 = incomingString.indexOf(',', plus4 + 1);
  int comma4 = incomingString.indexOf(',', comma3 + 1);

  // Extract Sender Address
  sendaddress = incomingString.substring(equal, comma1);
  // Extract Message Size
  messagesize = incomingString.substring(comma1 + 1, comma2); // message size lies between these two indexes
  // Extract Temperature
  Temperature = incomingString.substring(comma2 + 1 + 4, plus1); // message begins at (index after second comma), ends at (index after second comma + message size)
  // Extract Turbidity
  Turbidity = incomingString.substring(plus1 + 1, plus2);
  // Extract Voltage
  Voltage = incomingString.substring(plus2 + 1, plus3);
  // Extract Sample Period
  SamplePeriod = incomingString.substring(plus3 + 1, plus4);
  // Extract Packet Number
  PacketNo = incomingString.substring(plus4 + 1, comma3);
  //Extract RSSI
  rssi = incomingString.substring(comma3 + 1, comma4);
  // Extract SNR
  snr = incomingString.substring(comma4 + 1);

  PrintOLED(Temperature, Turbidity, Voltage, PacketNo, rssi, snr);
  
  PublishTemp(Temperature.toFloat());
  PublishTurb(Turbidity.toFloat());
  PublishVolt(Voltage.toFloat());
  PublishSamplePeriod();
  PublishRSSI(rssi.toFloat());
  PublishSNR(snr.toFloat());

  delay(100);
  digitalWrite(ledPin1, LOW);
}

void PrintOLED(String Temp, String Turb, String Volt, String PN, String rssi, String snr){
  OLEDcount += 1;
  display.setCursor(0, 5);
  display.clearDisplay();
  Volt = Volt.substring(0, Volt.length()-3);
  // Display static text
  display.println("Last Message:");
  display.println(" ");
  display.println("Temperature:  "+Temp+"*C");
  display.println("Turbidity:       "+Turb);
  display.println("Battery:         "+Volt+"%");
  display.println("Packet:           "+PN);
  // display.println("RSSI:            "+rssi);
  // display.println("SNR:             "+snr);
  // display.println("Tx State:       "+TxState);
  display.println("Sample Period:  "+SamplePeriod+"min");
  display.display(); 
}

void PublishTemp(float Temp){
    // Convert the value to a char array
    char tempString[8];
    dtostrf(Temp, 1, 2, tempString);
    client.publish("esp32/temperature", tempString);
}

void PublishTurb(float Turb){
    // Convert the value to a char array
    char turbString[8];
    dtostrf(Turb, 1, 2, turbString);
    client.publish("esp32/turbidity", turbString);
}

void PublishVolt(float Volt){
    // Convert the value to a char array
    char voltString[8];
    dtostrf(Volt, 1, 2, voltString);
    client.publish("esp32/battery", voltString);
}

void PublishRSSI(float rssi_){
    // Convert the value to a char array
    char rssiString[8];
    dtostrf(rssi_, 1, 2, rssiString);
    client.publish("esp32/rssi", rssiString);
}

void PublishSNR(float snr_){
    // Convert the value to a char array
    char snrString[8];
    dtostrf(snr_, 1, 2, snrString);
    client.publish("esp32/snr", snrString);
}

void PublishShutdown(){
    client.publish("esp32/shutdown", "Tx shutting down");
}

void UpdateTxStateLED(){
  if(TxState == "SLEEP"){
    digitalWrite(ledPin2, LOW);
    delay(100);
    client.publish("esp32/TxState", "sleep");
  }
  if(TxState == "WAKE"){
    digitalWrite(ledPin2, HIGH);
    delay(100);
    client.publish("esp32/TxState", "wake");
  } 
}

void ChangeSamplePeriod(){
  Serial.println("Changing sample period to " + NewSamplePeriod + " minutes");
  delay(2000);
  String Message = "AT+SEND=0," + String(NewSamplePeriod.length()+12) + ",CHANGESAMPLE" + NewSamplePeriod;
  Serial.println(Message);
  Serial.flush();
  
  // Publish Updated Period
  //PublishSamplePeriod();
}

void PublishSamplePeriod(){
  String SP = SamplePeriod;
  int str_len = SP.length() + 1;
  char char_array[str_len]; //buffer
  //SP.toCharArray(char_array, str_len);
  SP.toCharArray(char_array, str_len);
  client.publish("esp32/TxSamplePeriod", char_array);
}


void CheckClearToSend(){
  if (ClearToSend == true){
    if (QueuedSample == true){
      ChangeSamplePeriod();
      QueuedSample = false;
      delay(2000);
    }
    if (QueuedRestart == true){
      Serial.println("Restarting Tx");
      delay(2000);
      Serial.println("AT+SEND=0,7,RESTART");
      Serial.flush();
      QueuedRestart = false;
      delay(2000);
    }
  }
}

void ScreenSaver(){
    if (OLEDcount == 49){
    testfillrect();
    OLEDcount = 0;
  }
}

void testfillrect(void) {
  display.clearDisplay();

  for(int16_t i=0; i<display.height()/2; i+=3) {
    // The INVERSE color is used so rectangles alternate white/black
    display.fillRect(i, i, display.width()-i*2, display.height()-i*2, INVERSE);
    display.display(); // Update screen with each newly-drawn rectangle
    delay(1);
  }

  delay(2000);
}

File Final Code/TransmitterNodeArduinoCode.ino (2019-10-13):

// Temp Includes
#include <OneWire.h>
#include <DallasTemperature.h>

// Temp Constants and Objects
const int oneWireBus = 4;     
OneWire oneWire(oneWireBus);
DallasTemperature sensors(&oneWire);

// Turb Constant
const int turbPin = 34;

const int battPin = 33;

//Sensor Variables
float Temperature;
float Voltage;
int Turbidity;

// LoRa Tx Variables
#define ledPin1 2
//String str = "AT+SEND=";
//String Rx_address = "1";
String mess_length;
String temp;
String message;

// Text Extraction Variables
String incomingString;

// Tx State Variables
#define ledPin2 26
String TxState = "WAKE";

// Deep Sleep Variables
#define uS_TO_S_FACTOR 1000000  /* Conversion factor for micro seconds to seconds */
#define M_TO_S_FACTOR 60  /* Conversion factor for minutes to seconds */
// #define TIME_TO_SLEEP  5        /* Time ESP32 will go to sleep (in seconds) */
RTC_DATA_ATTR int SamplePeriod = 5; // minutes
RTC_DATA_ATTR int bootCount = 0;

void setup() {
  // Start the Serial Monitor
  Serial.begin(115200);
  delay(1000);

  // LED Setup
  pinMode(ledPin1, OUTPUT);
  pinMode(ledPin2, OUTPUT);

  // LoRa Tx setup
  Serial.println("AT+RESET");
  delay(20);
  Serial.println("AT+ADDRESS=0");
  delay(20);
  Serial.println("AT+NETWORKID=5");
  delay(200);

  //Increment boot number
  ++bootCount;

  // Tell Rx about Wake
  TxState = "WAKE";
  digitalWrite(ledPin2, HIGH);
  SendState();
  delay(2000);
  
  // Temp Setup
  sensors.begin();
  delay(50);

  // Transmit Data
  LoRaTx();
  delay(2000);

  // Listen to Tx
  Serial.println("AT+SEND=1,12,CLEARTOSEND");
  delay(2000);
  
  // Listen
  for (int i=1; i<10; i=i+1){
      CheckForMessage();
      delay(1000);
  }

  delay(2000);
  CheckBattery();
  delay(2000);

  // Configure wake up source
  esp_sleep_enable_timer_wakeup(SamplePeriod * uS_TO_S_FACTOR * M_TO_S_FACTOR);
  Serial.println("Setup ESP32 to sleep for " + String(SamplePeriod) + " minute(s)");
  delay(3000);
  
  // Tell Rx about Sleep
  TxState = "SLEEP";
  digitalWrite(ledPin2, LOW);
  SendState();
  delay(2000);

  // Enter Deep Sleep
  Serial.println("Going to sleep now");
  Serial.flush(); 
  esp_deep_sleep_start();
  Serial.println("This will never be printed");
  
}

void loop() {
    //This will never be called
}



void LoRaTx(){
  GetAllReadings();
  message = CreateMessage();
  Serial.println(message);
  Serial.flush();
  delay(2000);
  
  digitalWrite(ledPin1, HIGH);
  delay(100);
  digitalWrite(ledPin1, LOW);
}

String CreateMessage(){
  String temp = String(Temperature);
  String volt = String(Voltage);
  String turb = String(Turbidity);
  String count = String(bootCount);
  
  mess_length = temp.length() + turb.length() + volt.length() + count.length() + String(SamplePeriod).length() + 4 + 4;
  message = "AT+SEND=1," + mess_length + ",DATA"+ temp + "+" + turb + "+" + volt + "+" + String(SamplePeriod) + "+" + count;
  return message;
}


void SendState(){
  String message = "AT+SEND=1," + String(TxState.length()+5) + ",STATE" + TxState;
  Serial.println(message);
  Serial.flush();
}

void CheckForMessage(){
  if (Serial.available()>0){

    incomingString = Serial.readString();
  
    if(incomingString.indexOf("RCV") > 0){
      Serial.println(incomingString);
      // Filter Messages
      // Data
      if(incomingString.indexOf("CHANGESAMPLE") > 0){
        int beginning = incomingString.indexOf("CHANGESAMPLE") + 12;
        int comma = incomingString.indexOf(',', beginning + 1);
        String SP_string = incomingString.substring(beginning, comma);
        Serial.println("Changing Sample Period to " + SP_string + " minute(s)");
        SamplePeriod = SP_string.toInt();
      }

      // Restart
      if(incomingString.indexOf("RESTART") > 0){
        Serial.println("Tx entering forced restart");
        delay(1000);
        ESP.restart();
      }

    }
  }
}

void GetAllReadings(){
  // Temperature
  sensors.requestTemperatures(); 
  float temperatureC = sensors.getTempCByIndex(0);
  Temperature = temperatureC;

  //Battery Voltage
  float batteryLevel = map(analogRead(battPin), 0.0f, 4095.0f, 0, 100);
  float UC_percent = (batteryLevel-80)*5;   // UC = Usable Capacity
  Voltage = UC_percent;

  // Turbidity
  Turbidity = analogRead(turbPin);
}

void CheckBattery(){
  if (Voltage <= 15){
    Serial.println("AT+SEND=1,8,SHUTDOWN");
    delay(3000);
    Serial.println("Battery drained - shutting down");
    delay(3000);
    esp_deep_sleep_start();
  }
}

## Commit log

2019-08-05 Add files via upload
    Simple test of REYAX LoRa modules with ESP32's. Transmitter sends "Hello!" and blinks LED. If receiver receives "Hello!", blinks LED.
2019-08-05 Add files via upload
    Fritzing model of test circuit.
    [LoRa Tx and Rx Test 1.fzz]
2019-08-05 Add files via upload
    Simple test circuit of DFRobot DS18B20 Digital Temperature Sensor using ESP32. Reads sensor and prints data to serial port.
    [Temperature Sensor Circuit.fzz]
2019-08-05 Add files via upload
    Simple test circuit of DFRobot Analogue/Digital Turbidity Sensor using ESP32. Reads sensor and prints data to serial port. Folder contains Arduino code and Fritzing models for the sensor and test cir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
    [Turbidity Sensor Circuit.fzz, Turbidity Sensor.fzz]
2019-08-05 Add files via upload
    Initial draft budget to get an idea.
    [1. Initial Draft Budget.xlsx]
2019-08-05 Add files via upload
    Final budget with South African suppliers. This budget was not ordered.
    [2. Final Budget (SA Suppliers).xlsx]
2019-08-05 Add files via upload
    Final budget, ordered from Mouser and Amazon (USA).
    [3. Final Budget.xlsx]
2019-08-05 Add files via upload
    Updated budget to include batteries and power management circuitry. These items were bought in ZAR, so the previous "Final Budget" was converted to ZAR and merged.
    [4. Updated Budget.xlsx]
2019-10-13 Create Node_RED Flow
2019-10-13 Rename Node_RED Flow to Node-RED Flow
